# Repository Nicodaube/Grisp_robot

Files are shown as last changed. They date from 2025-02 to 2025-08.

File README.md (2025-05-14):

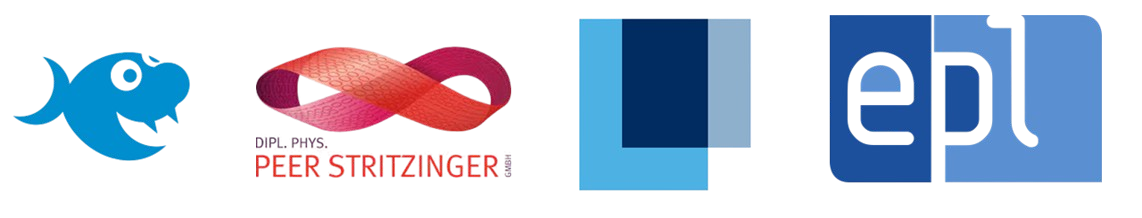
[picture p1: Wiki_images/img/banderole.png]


# GRiSP2 Robot

## Introduction

This project is an extension of the master thesis made by Francois Goens and Cédric Ponsard (link [here](https://github.com/FrancoisGgg/balancing_robot) (2023-2024)). It is done in the context of a new master thesis by Nicolas Daube and Thomas Vanbever (2024-2025). Both of these master thesis where done under the supervision of Prof. Peter Van Roy at UCLouvain. The goal of this project is to use [GRISP2 boards](https://github.com/grisp/grisp) (designed and comercialised by [Peer Stritzinger GMBH.](https://stritzinger.com/)) and the [Hera](https://github.com/Nicodaube/hera) framework to create a robot capable of standing upright (last master thesis) and to know its own position in an assembly of rooms (current project). The robot, and its associated sensors, need to know at all time the position of the robot in the system of rooms. Each sensor knows all the data sent by each sensors and by the robot. An other goal of this project is thus to allow each sensor to compute the position of the robot (using a Kalman Filter) at a reasonable rate. This implies that the filter must evolve over time, using the data given by the right sensors at the right time.

The project is done using Erlang OTP (current version 27.2.4). If you want more informations about the, project, visit our the [Wiki](https://github.com/Nicodaube/Grisp_robot/wiki) section of this repository.

## Organisation

This repository is organised in several subdirectories :

* **Hardware_robot** : contains all the necessary files to build the robot. In `Hardware_robot/printing_files` you will find all the files for the prints in 3D and the laser cuts.
* **Hardware_sensor** : Contains all the necessary files to build the sensors and their supports.
* **Laptop_controller** : contains all the code concerning the python server and controller for the robot. Note that its use is mandatory to have a fully functional system.
* **LilyGo_software** : contains all the code for the two LilyGO used in this project. They are used for communication between the robot and the controller.
* **Wiki_image** : just a directory containing all the wiki and README images.
* **balancing_robot** : contains all the code for the auto-stabilized robot.
* **electronics**: contains the files concerning the custom PCB designed for the robot.
* **sensor**: contains all the erlang code for the implementation of the sonar sensors.

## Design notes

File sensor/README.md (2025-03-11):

sensor
=====

A GRiSP application

Build
-----

    $ rebar3 compile

Deploy
------

    $ rebar3 grisp deploy -n <name> -v <version>

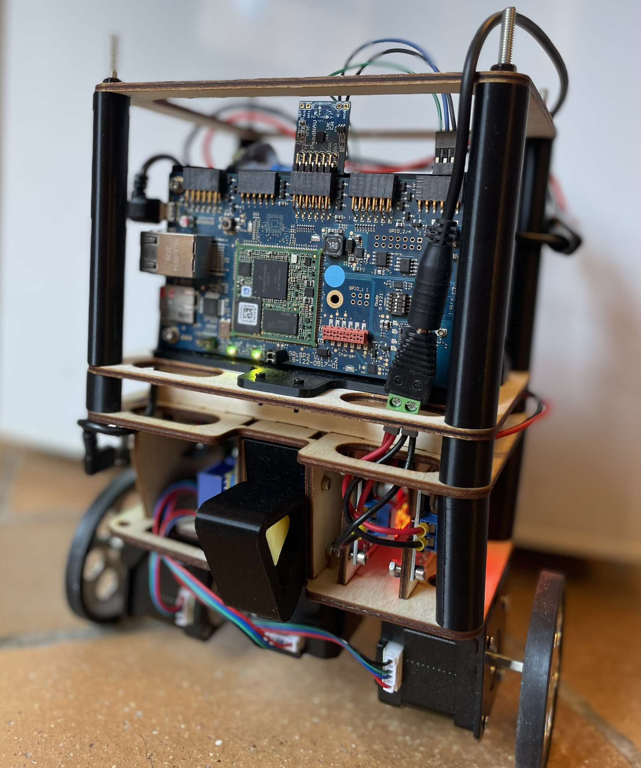
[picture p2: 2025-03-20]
Wiki_images/img/Robot.jpg

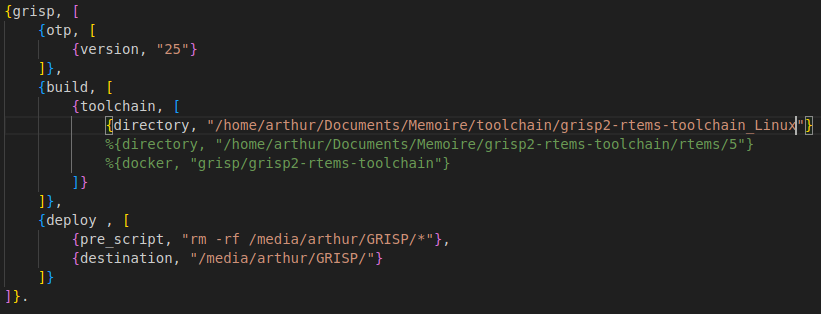
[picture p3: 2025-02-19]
Wiki_images/img/toolchain.png

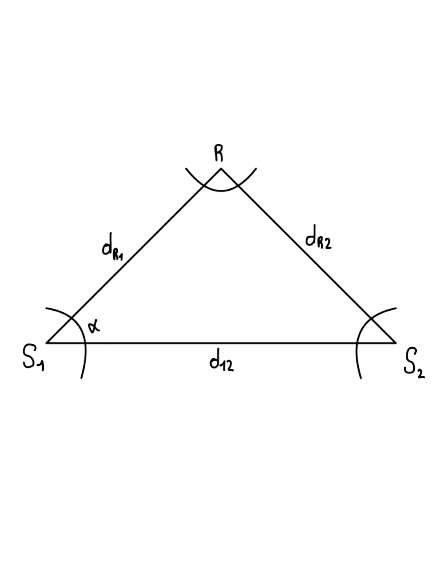
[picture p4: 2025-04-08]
Wiki_images/img/CosineLaw.png

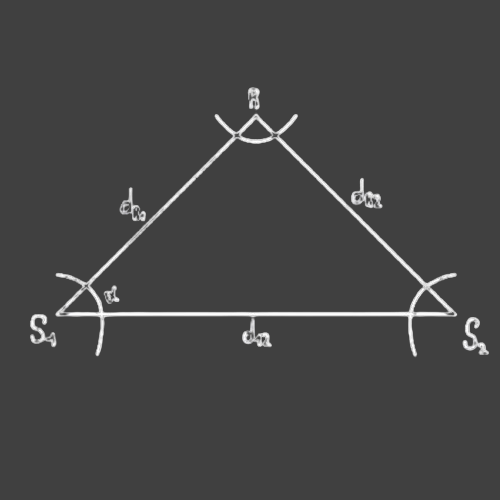
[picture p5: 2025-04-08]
Wiki_images/img/CosineLaw2.png

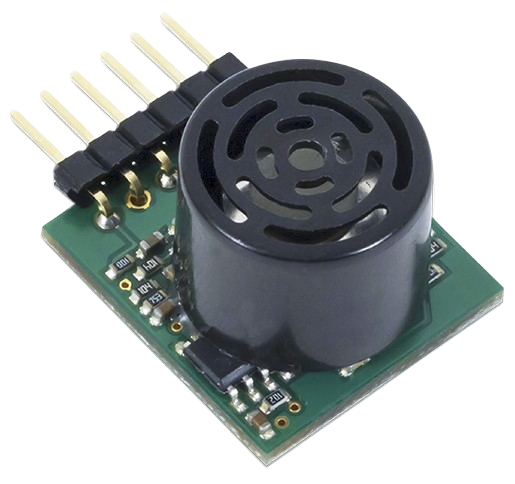
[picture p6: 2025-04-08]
Wiki_images/img/Pmod_sonar.png

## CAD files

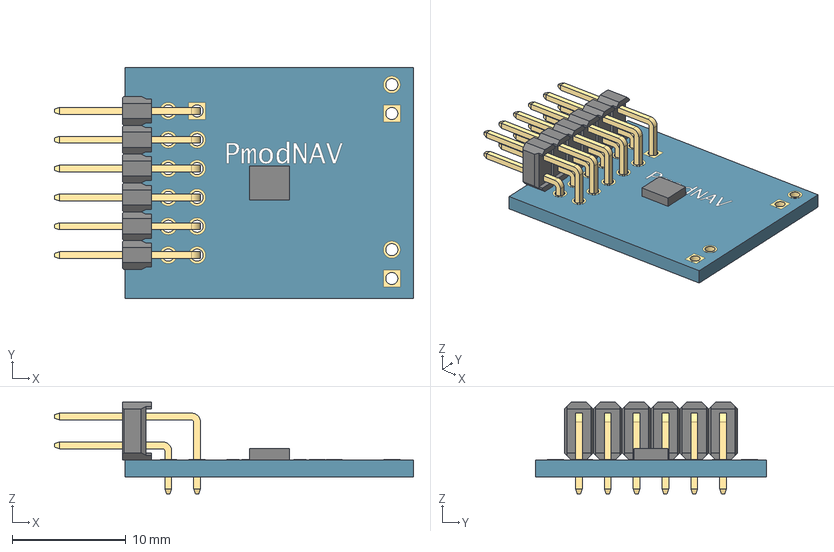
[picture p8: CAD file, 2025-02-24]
Hardware_robot/pmodnavstep/PmodNAV.stp
31.6 x 20.3 x 8.08 mm

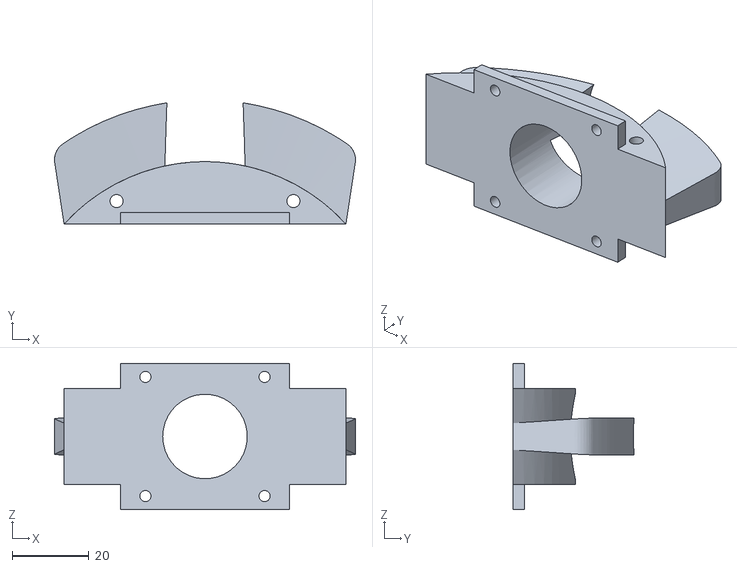
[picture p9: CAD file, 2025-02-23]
Hardware_robot/Printing_files/3D/A.STL
78.3 x 31.5 x 38.0

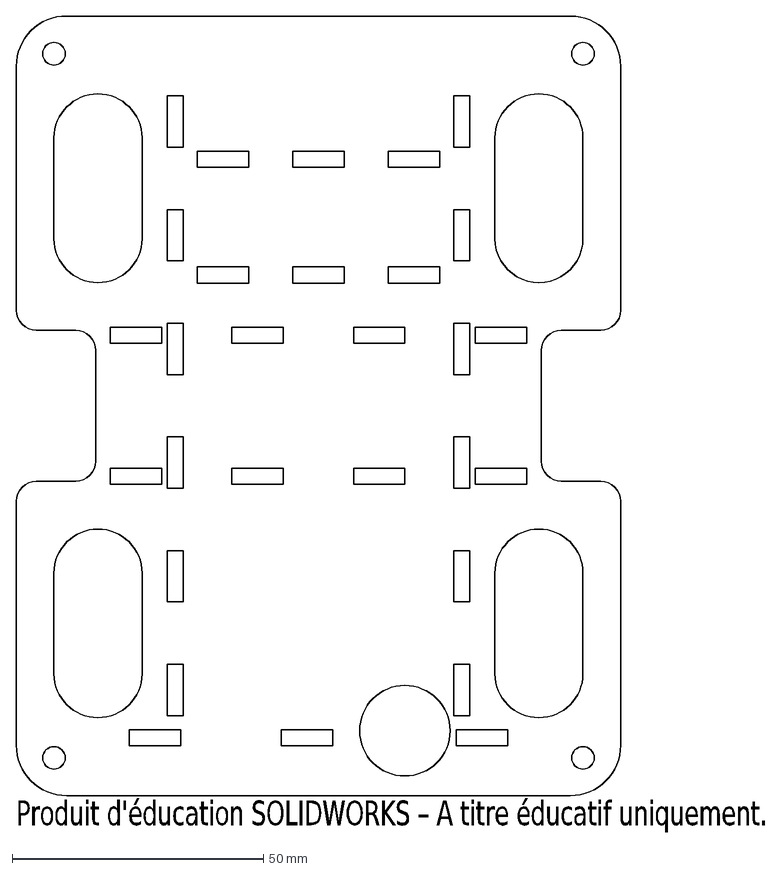
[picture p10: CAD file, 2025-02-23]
Hardware_robot/Printing_files/Laser/F.dxf
Produit d'éducation SOLIDWORKS – A titre éducatif uniquement.

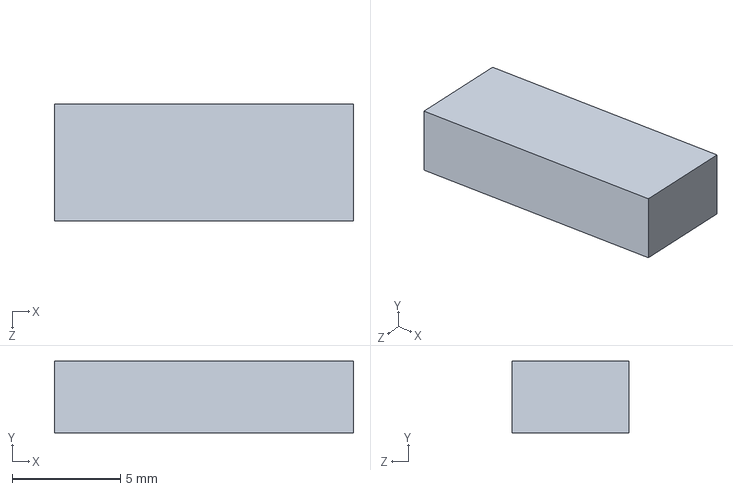
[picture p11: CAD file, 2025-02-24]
Hardware_robot/TTGO LORA32 T3 V1.6.1/antenna block.SLDPRT
13.8 x 3.30 x 5.40 mm

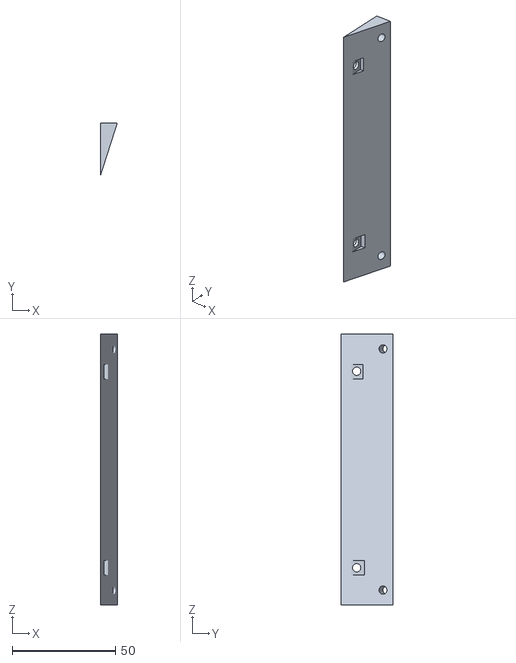
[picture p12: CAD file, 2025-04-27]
Hardware_Sensor/3D/Iece_change v11.stl
8.00 x 25.0 x 131.0

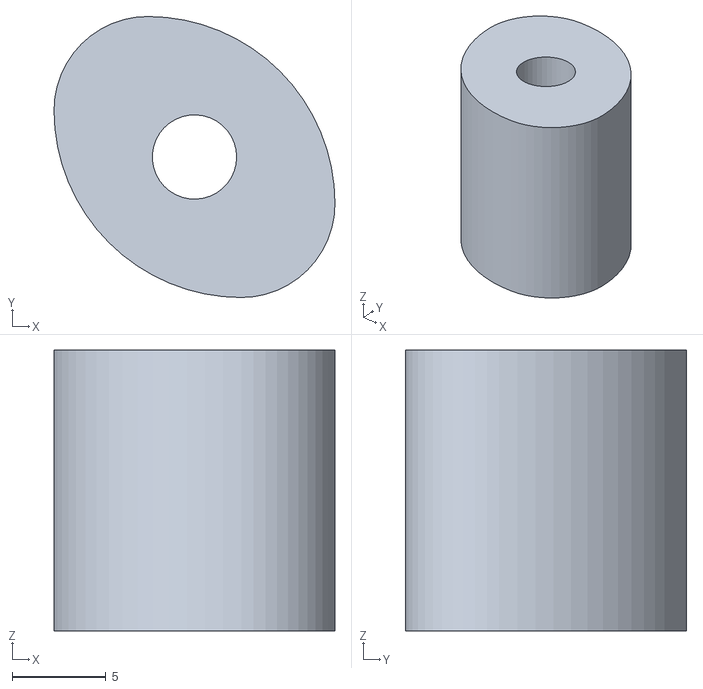
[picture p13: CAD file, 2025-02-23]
Hardware_robot/Printing_files/3D/Fx4.STL
15.0 x 15.0 x 15.0

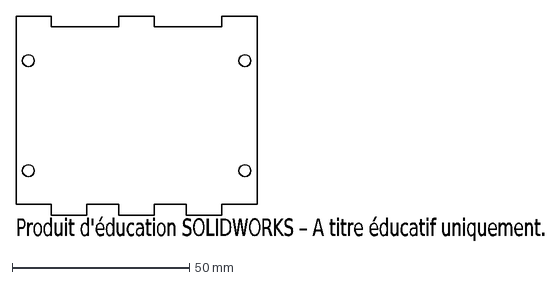
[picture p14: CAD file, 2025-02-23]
Hardware_robot/Printing_files/Laser/E.DXF
Produit d'éducation SOLIDWORKS – A titre éducatif uniquement.

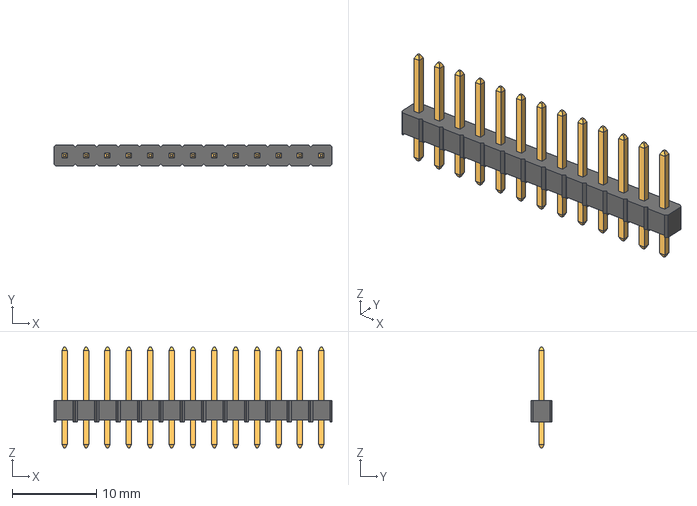
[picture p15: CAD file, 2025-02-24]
Hardware_robot/TTGO LORA32 T3 V1.6.1/13-Pin Header - Male - 2.54mm.step
33.0 x 2.54 x 11.9 mm

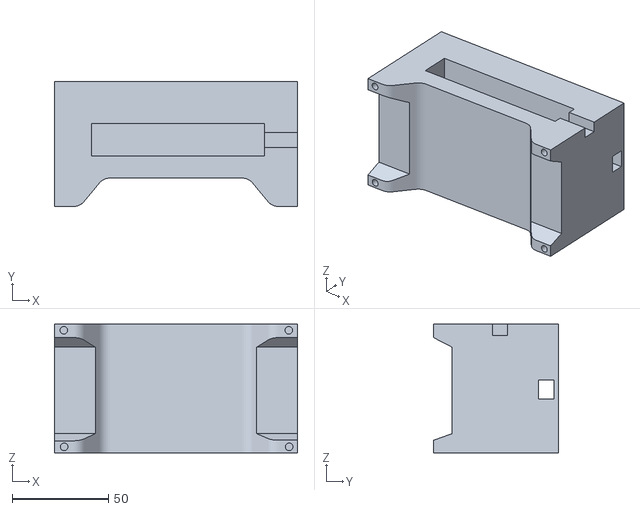
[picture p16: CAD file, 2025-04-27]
Hardware_Sensor/3D/Sensor_piece v15.stl
126.5 x 65.0 x 67.0

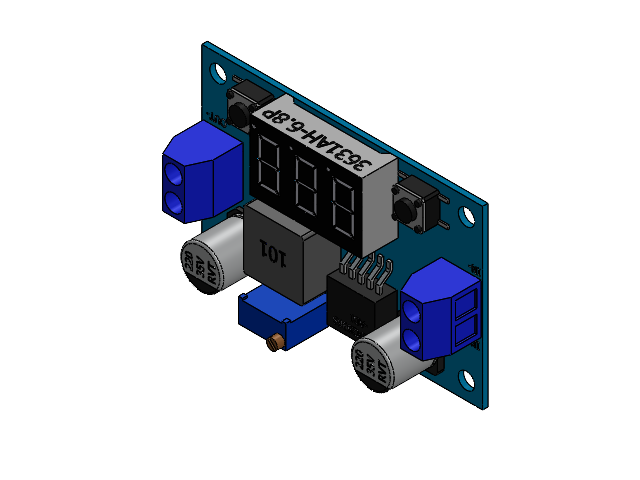
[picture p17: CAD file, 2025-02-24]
Hardware_robot/CAD_robot/CN2596-2_V2.SLDASM
CN2596-2_1.stp
LM2596S-ADJ.stp
3631AH-6.8P.stp
PZ_PushButton.stp x 2
Trimpot_3296W.stp
CAPAE-D8.0x10.2.stp x 2

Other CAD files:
Hardware_robot/CAD_robot/TerminalBlock_Phoenix_MKDS-1,5-2-5.08_1x02_P5.08mm_Horizontal.SLDASM
Hardware_robot/CAD_robot/PinHeader_1x10_P2.54mm_Vertical.SLDASM
Hardware_robot/CAD_robot/PinHeader_2x06_P2.54mm_Vertical_1.SLDASM
Hardware_robot/CAD_robot/PinHeader_1x04_P2.54mm_Vertical.SLDASM
Hardware_robot/CAD_robot/PinSocket_2x06_P2.54mm_Vertical_1.SLDASM
Hardware_robot/CAD_robot/PCB_V2.SLDASM
Hardware_robot/CAD_robot/PCB_V2 PCB2.SLDPRT
Hardware_robot/CAD_robot/Bat_lat.SLDPRT
Hardware_Sensor/3D/Support coin_attache v2.stl
Hardware_robot/CAD_robot/17HE15-1504S.SLDPRT
Hardware_robot/CAD_robot/17HE15-1504S.STEP
Hardware_robot/CAD_robot/BOOST.SLDPRT
Hardware_robot/CAD_robot/Bat_top.SLDPRT
Hardware_robot/CAD_robot/BatteryPackBlue.SLDPRT
Hardware_robot/CAD_robot/Bevel_rack.SLDPRT
Hardware_robot/CAD_robot/CN2596-2.stp
Hardware_robot/CAD_robot/Coll_1.SLDPRT
Hardware_robot/CAD_robot/Coll_2.SLDPRT
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

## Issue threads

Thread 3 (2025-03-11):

[SENSORS] Automatic binding of sensors

Nicodaube, 2025-03-11:
The sensors need to be able to register to the server (Laptop) and to get access to all the other sensors.

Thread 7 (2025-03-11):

[SENSORS] Hera integration

Nicodaube, 2025-03-11:
Integrate the hera framework and hera com to do the communication and the kalman filter computing.

Closed 2025-04-08.

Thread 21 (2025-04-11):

[SENSOR] Sonar Syncing

Nicodaube, 2025-04-11:
The sensors need to synchronyze their measures to avoid disturbance.

Closed 2025-04-14.

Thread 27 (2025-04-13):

[ROBOT] Gather Robot and nav data

Nicodaube, 2025-04-13:

Nicodaube, 2025-05-27:
We'll need all those data for the kalman implementation :

-  Acceleration in X,Y,Z
-  Angular velocity in X, Y, Z
-  Sonars ground distances
-  Sonars angles
-  Robot initial position (X, Y, angle)

May be used to improve computation :
- Robot angle

Closed 2025-06-14.

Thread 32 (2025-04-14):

[SENSOR] Error with persistent_term:get on configuration

Nicodaube, 2025-04-14:

Nicodaube, 2025-04-21:
Seems to have dissapeared

Closed 2025-04-21.

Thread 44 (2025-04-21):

[SENSOR] [ROBOT] Create basic new kalman filter

Nicodaube, 2025-04-21:

Vanboucle, 2025-04-28:
We need to create a function to capture the correct sonar values in order to create the quaternion matrices. Then we need to retrieve all the values from the robot. Speed, acceleration, angular velocity. So that we know where it is in space.

Closed 2025-06-14.

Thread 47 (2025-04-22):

[3D ]Pieces use for the sensor

Vanboucle, 2025-04-22:
We have separated the sensor part into 3 different parts. The first is fixed to the wall. The second is the main part where the battery, the Boost controller and the GRISP card will be placed. The last part is the part that we can modify relatively easily in order to change the angle of inclination of the sonars.

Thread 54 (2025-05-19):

[SENSOR][ROBOT] Correct angle computation

Nicodaube, 2025-05-19:
The angle of at which the robot is at is currently wrong. The initial theory is that it is because it doesn't take into account the initial angle of the robot

Nicodaube, 2025-05-19:
There is a problem with the sonars, maybe it is because of the synchronization between them. I think one of the sensors is starving. I get here a sensor who computed 40 times the distance while the other only computed it 11 times. I must then improve the synchronization system.

Closed 2025-05-22.

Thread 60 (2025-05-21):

[SENSOR] Possible bug when hera_measure crashes

Nicodaube, 2025-05-21:
When a hera_measure module crashes, it restarts with a sequence num = 1, it should restart with the latest seq number

Nicodaube, 2025-05-21:
Possibly connected to issue #56

Nicodaube, 2025-05-21:
Solved for sonar sensor, may need to do it for the other hera_measure as well

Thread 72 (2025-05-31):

[ROBOT][SENSOR] Find a way and implement the communication inside/outside the Farraday's cage

Nicodaube, 2025-05-31:

Nicodaube, 2025-05-31:
For the communication outside to inside the cage, we can either use Ethernet port or use one of the port available on the GRiSP (UART/SPI), then we need to implement an additional way of communicating to the robot (local wifi ? An other type of IoT communication as LOra or Bluetooth ?)

Nicodaube, 2025-05-31:
The idea, for now, would be to create a local WiFI connection inside the cage using an ESP32 as router. I need to implement a switch for the sensors and the robot to switch between different connections as they go. The sensors need to try to connect to the general connection and switch to the local inside cage connection if the general connection is unavailable.

For the connection outside/inside, there are multiple possibilities. I can either create a wired connection between the sensors outside the cage and inside the cage, or use the robot as a relay (caching the latest datas and transmitting them to the sensors once inside). The problem that i see with that solution is the fact that I don't know how to contact the server if the inside is completly cut out from the outside of the cage. I then think that I need to use the wired connection and transmit all data as a gossip between sensors in different networks.

Closed 2025-07-29.

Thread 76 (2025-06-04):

[???HOTSPOT???] Implement LilyGo Hotspot

Nicodaube, 2025-06-04:
Implement the ESP32 lilygo software that will allow it to become a hotspot available for the sensors to connect to.

Nicodaube, 2025-07-01:
closed in previous pull request

Closed 2025-07-01.

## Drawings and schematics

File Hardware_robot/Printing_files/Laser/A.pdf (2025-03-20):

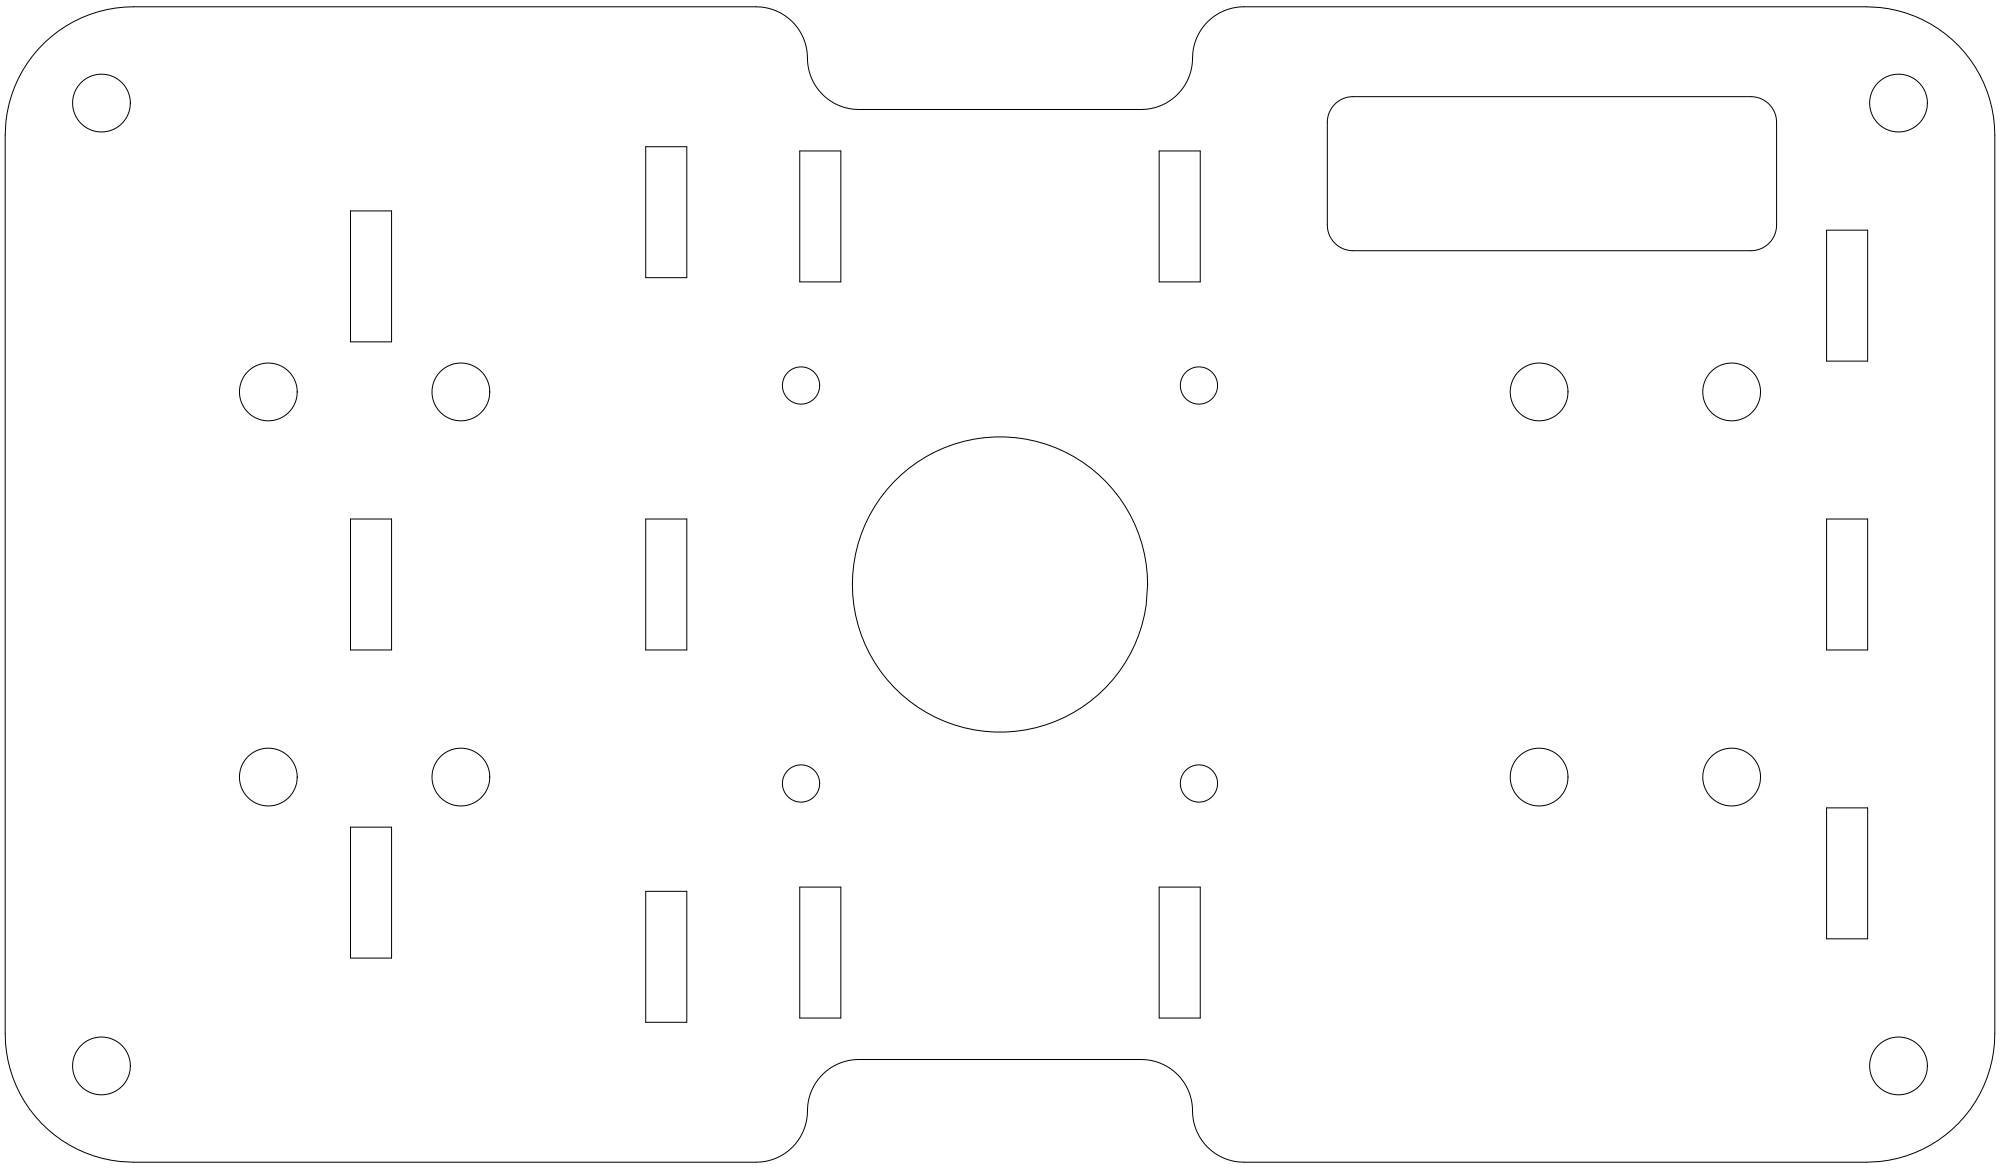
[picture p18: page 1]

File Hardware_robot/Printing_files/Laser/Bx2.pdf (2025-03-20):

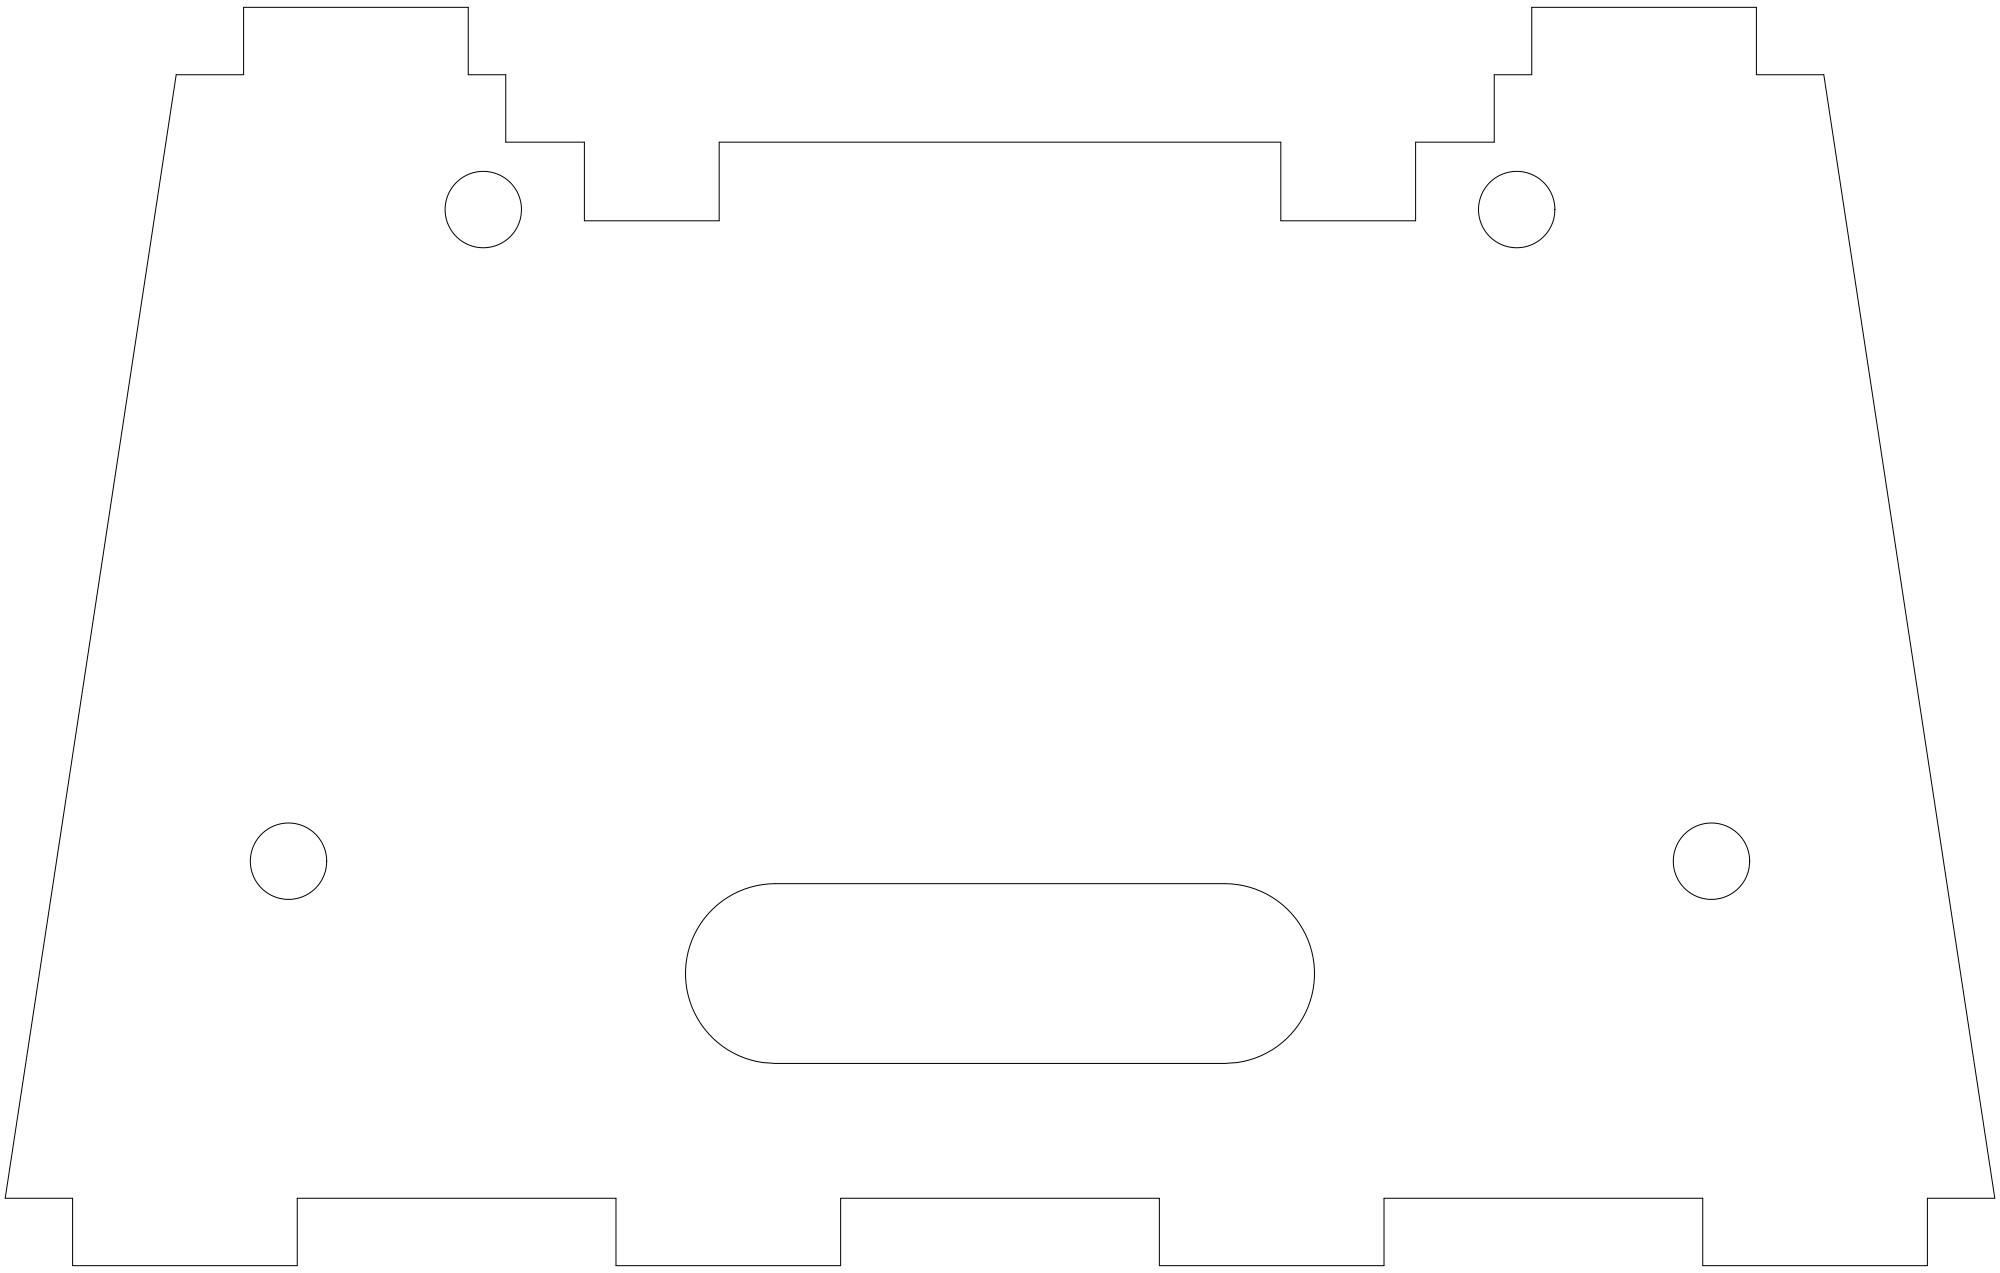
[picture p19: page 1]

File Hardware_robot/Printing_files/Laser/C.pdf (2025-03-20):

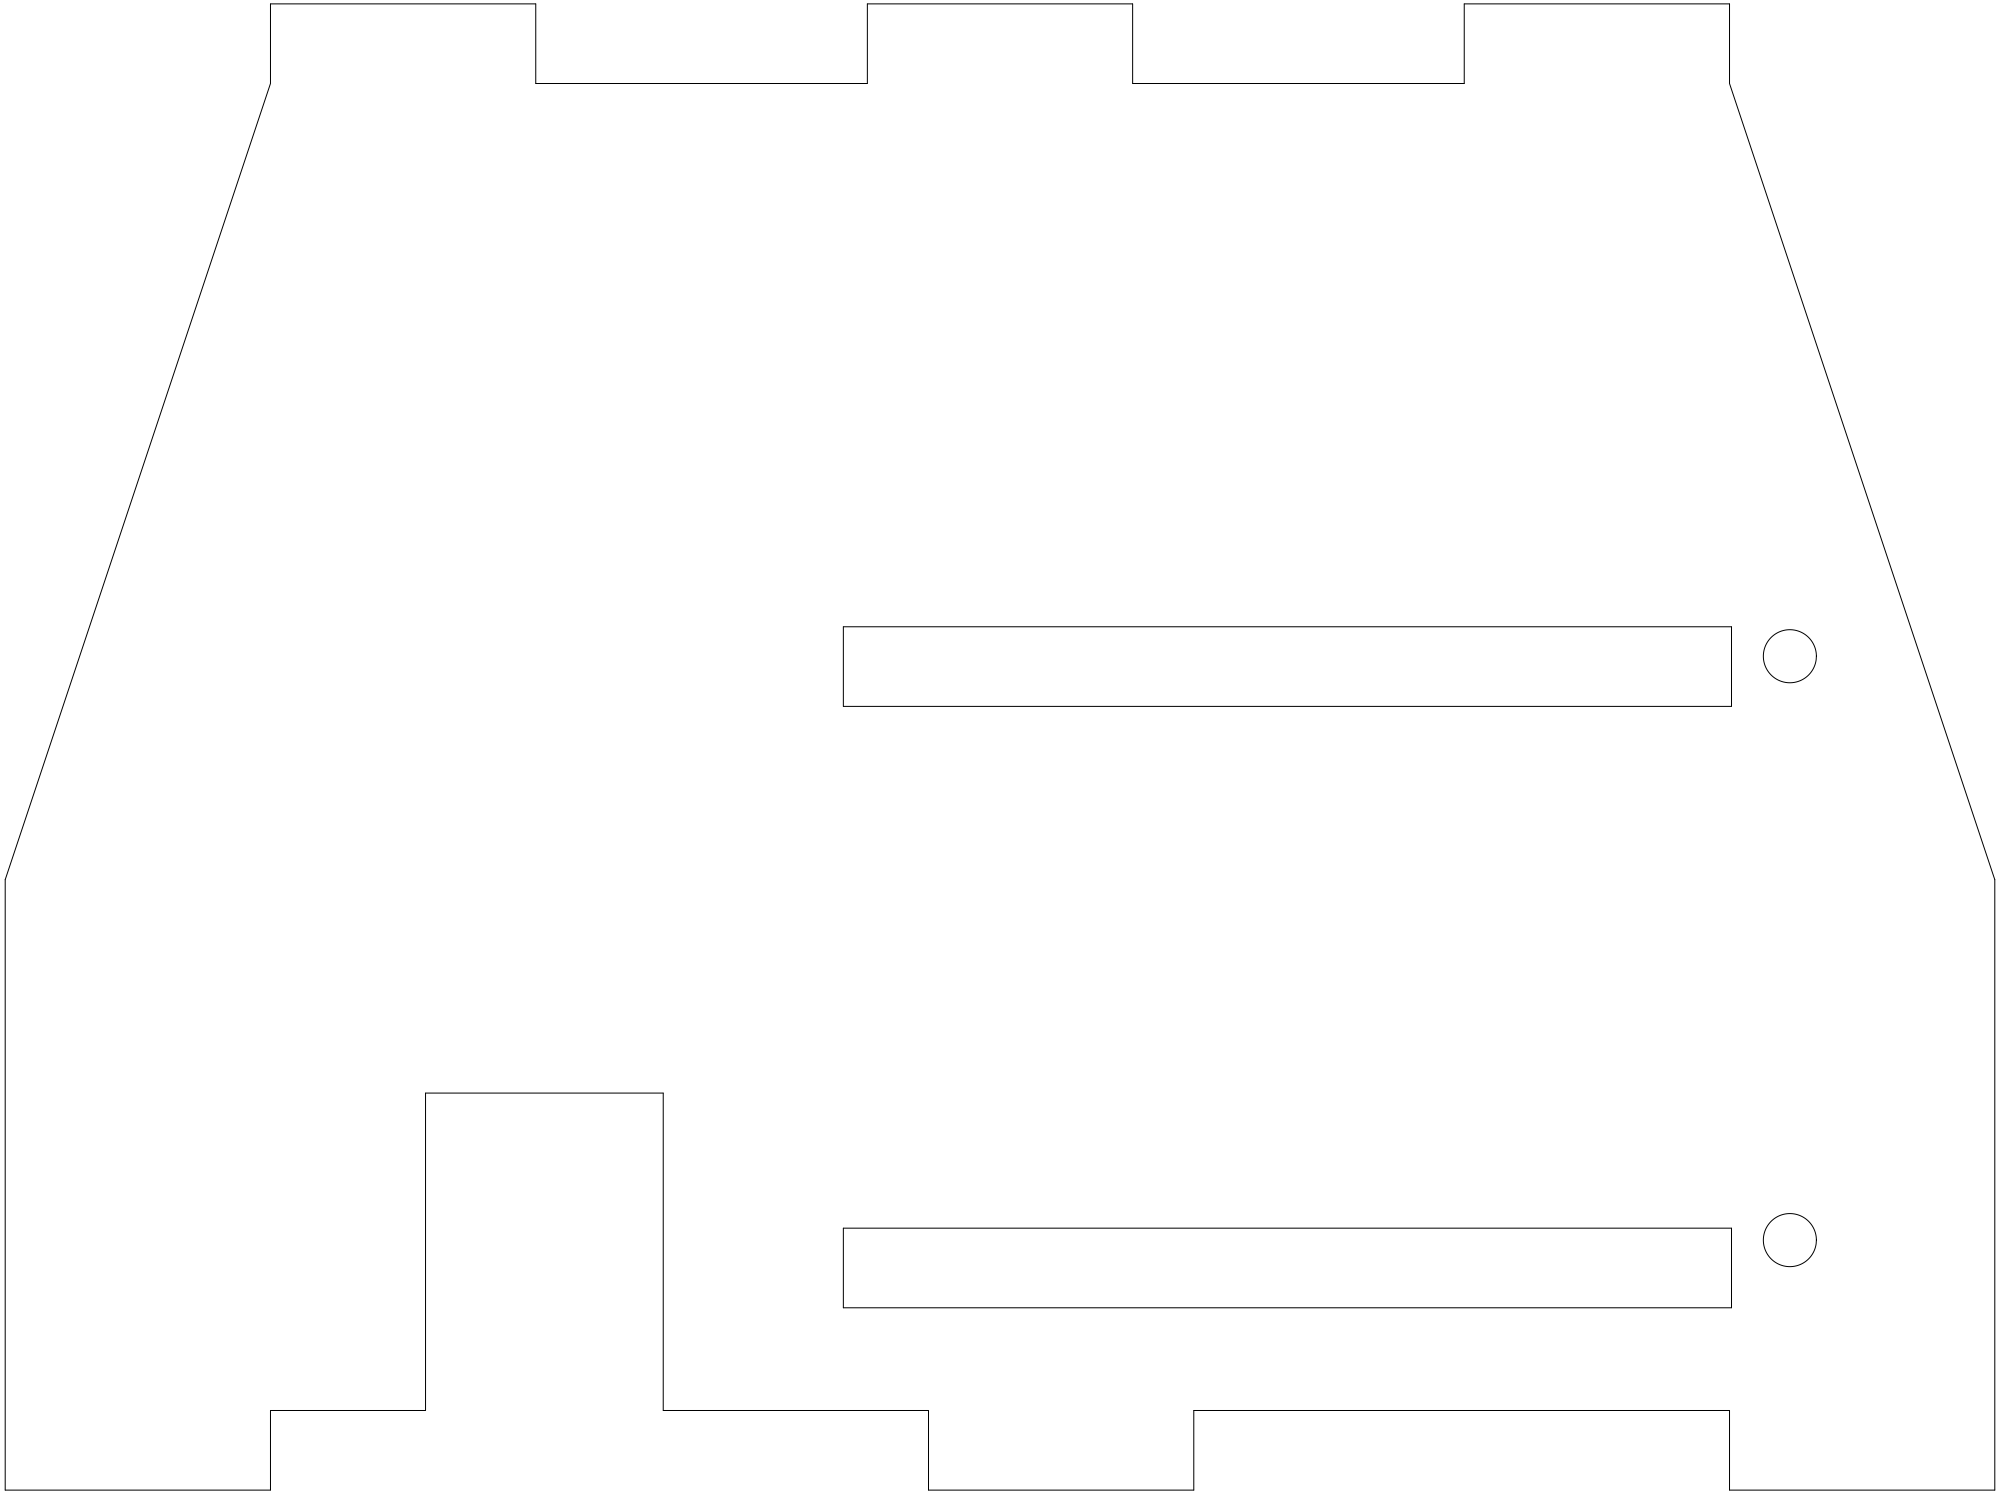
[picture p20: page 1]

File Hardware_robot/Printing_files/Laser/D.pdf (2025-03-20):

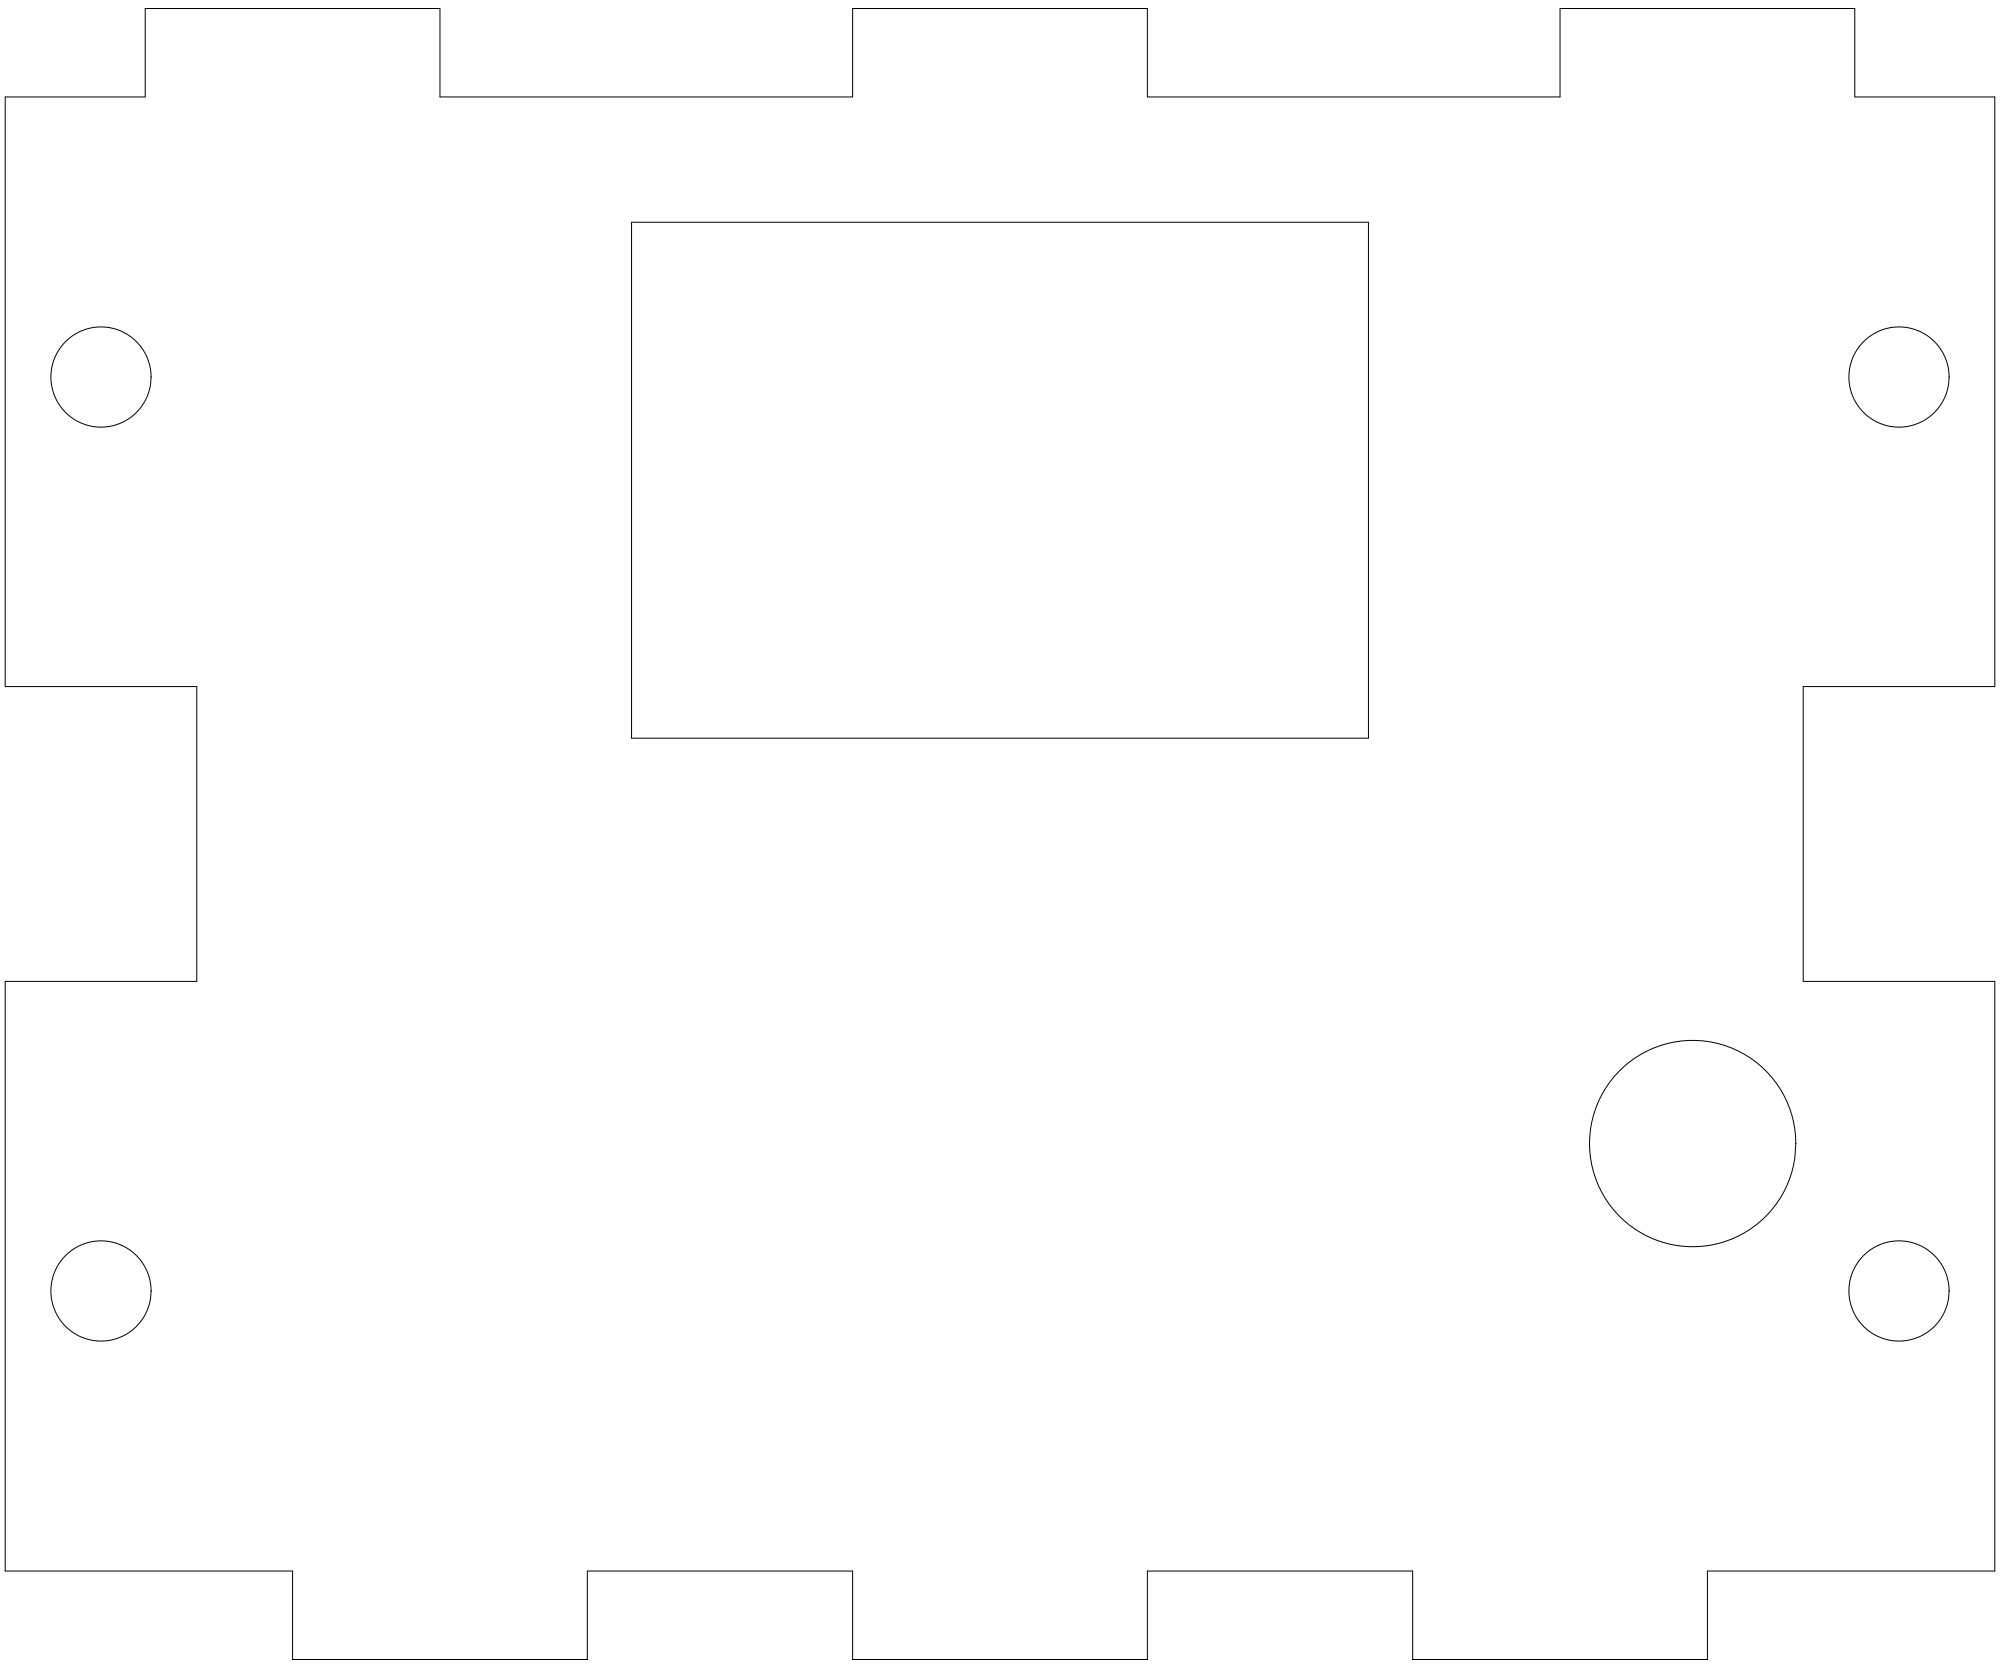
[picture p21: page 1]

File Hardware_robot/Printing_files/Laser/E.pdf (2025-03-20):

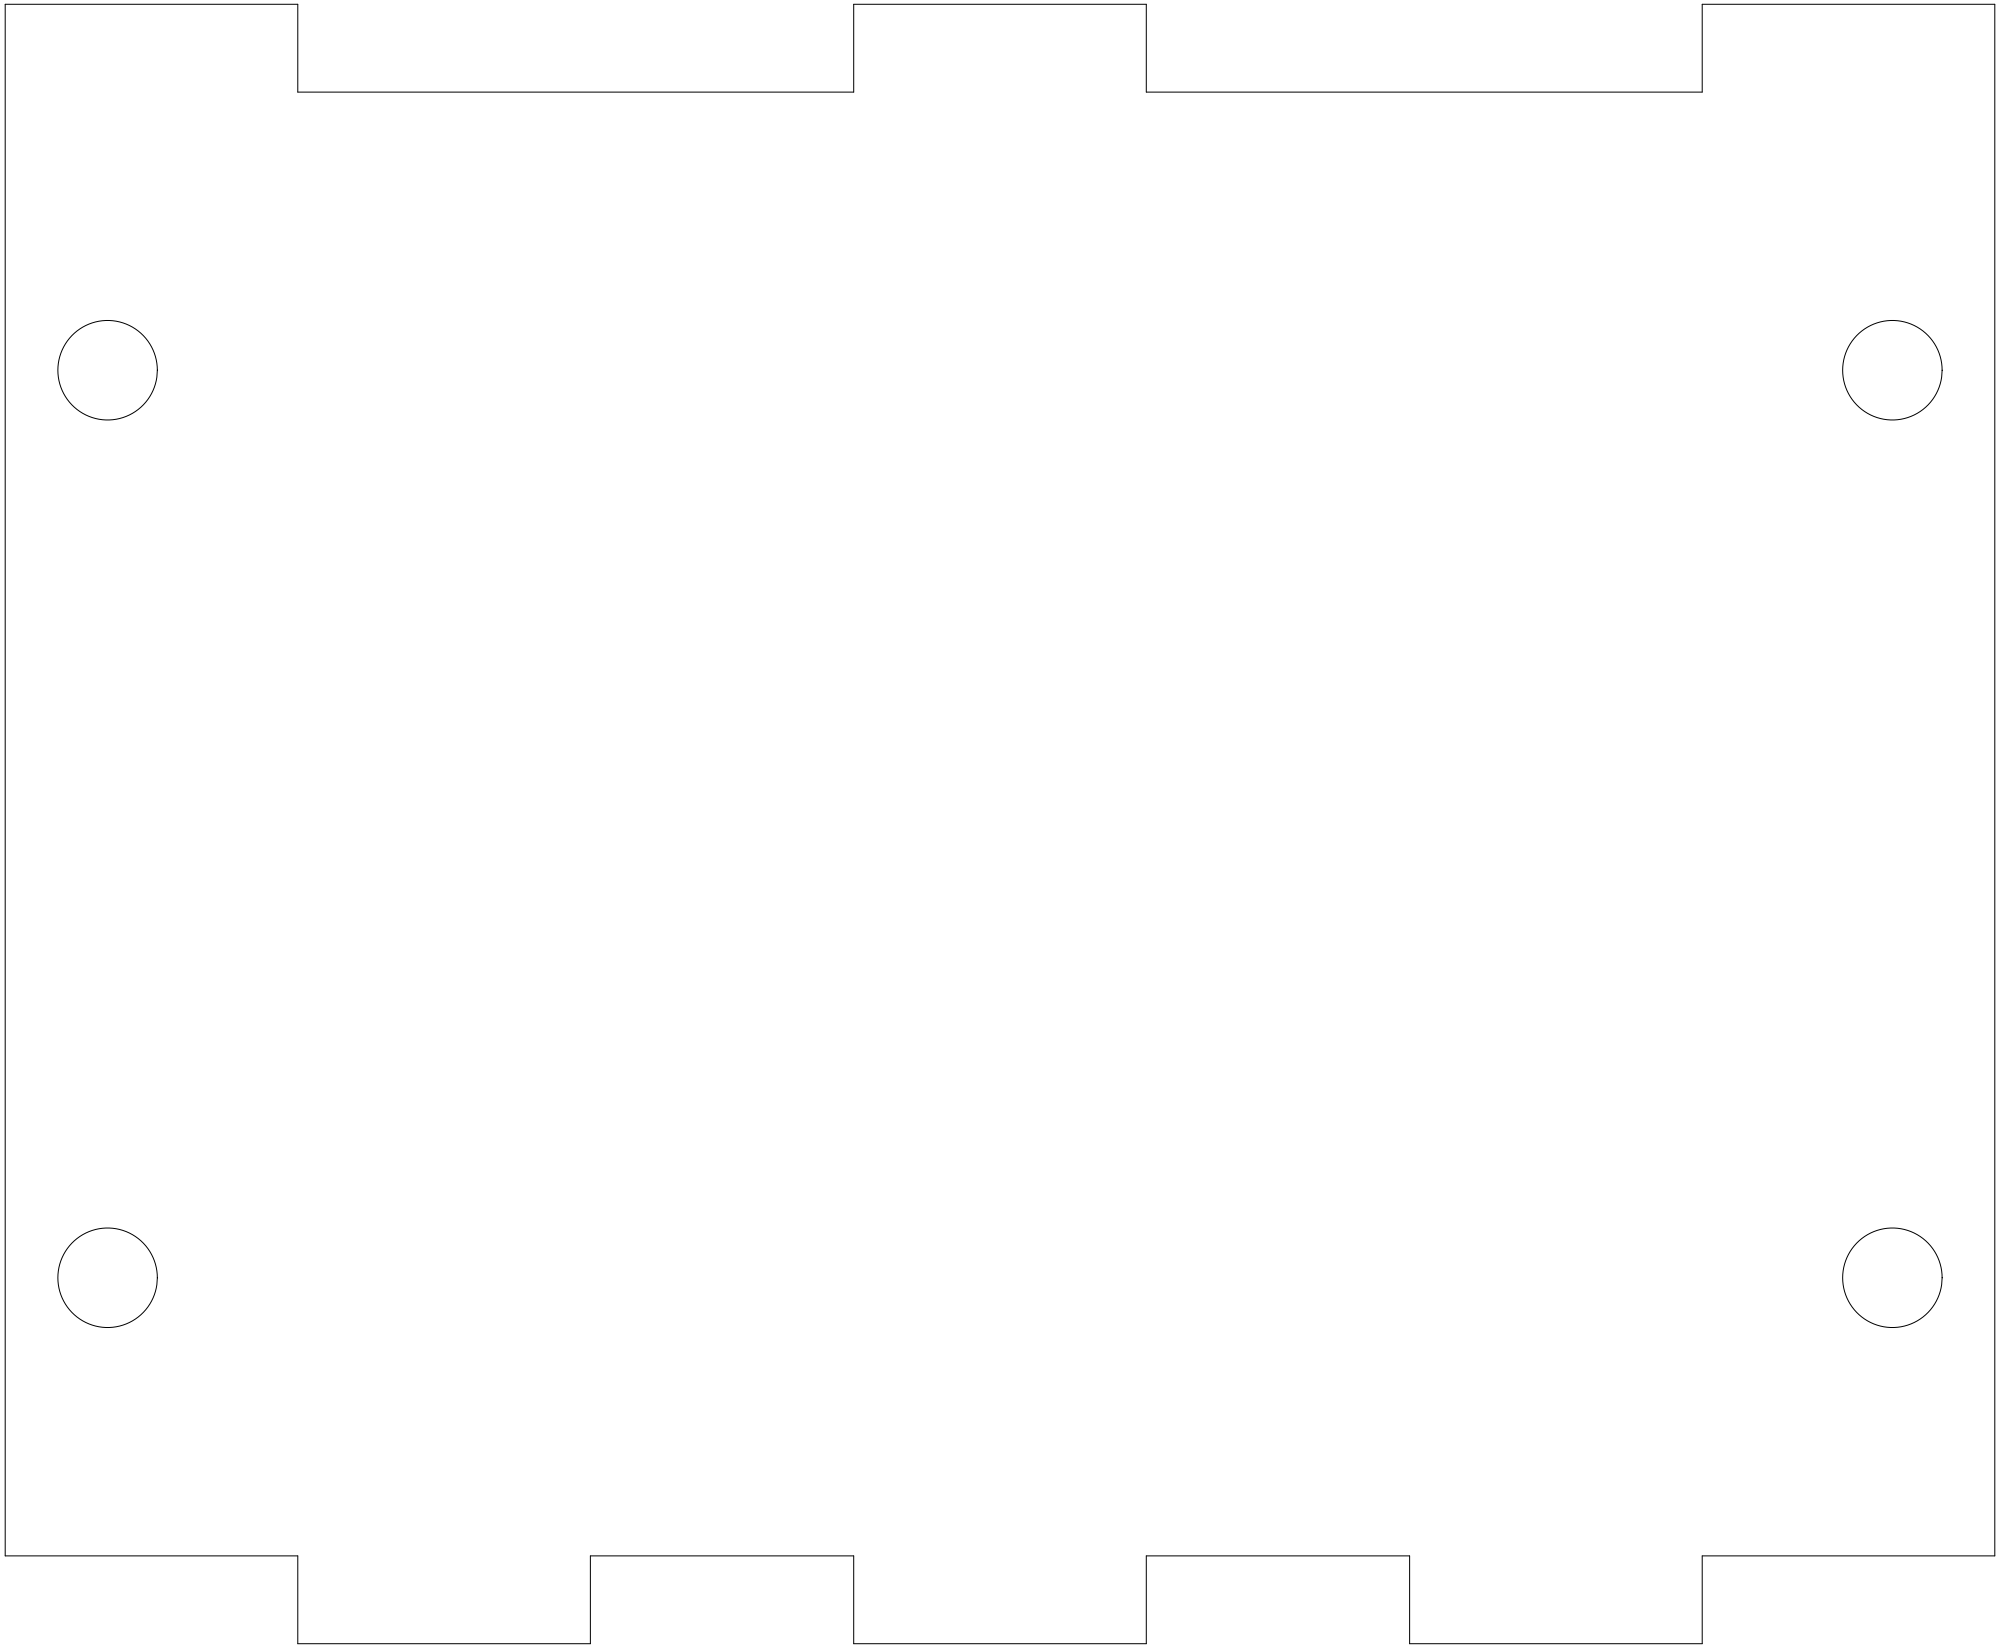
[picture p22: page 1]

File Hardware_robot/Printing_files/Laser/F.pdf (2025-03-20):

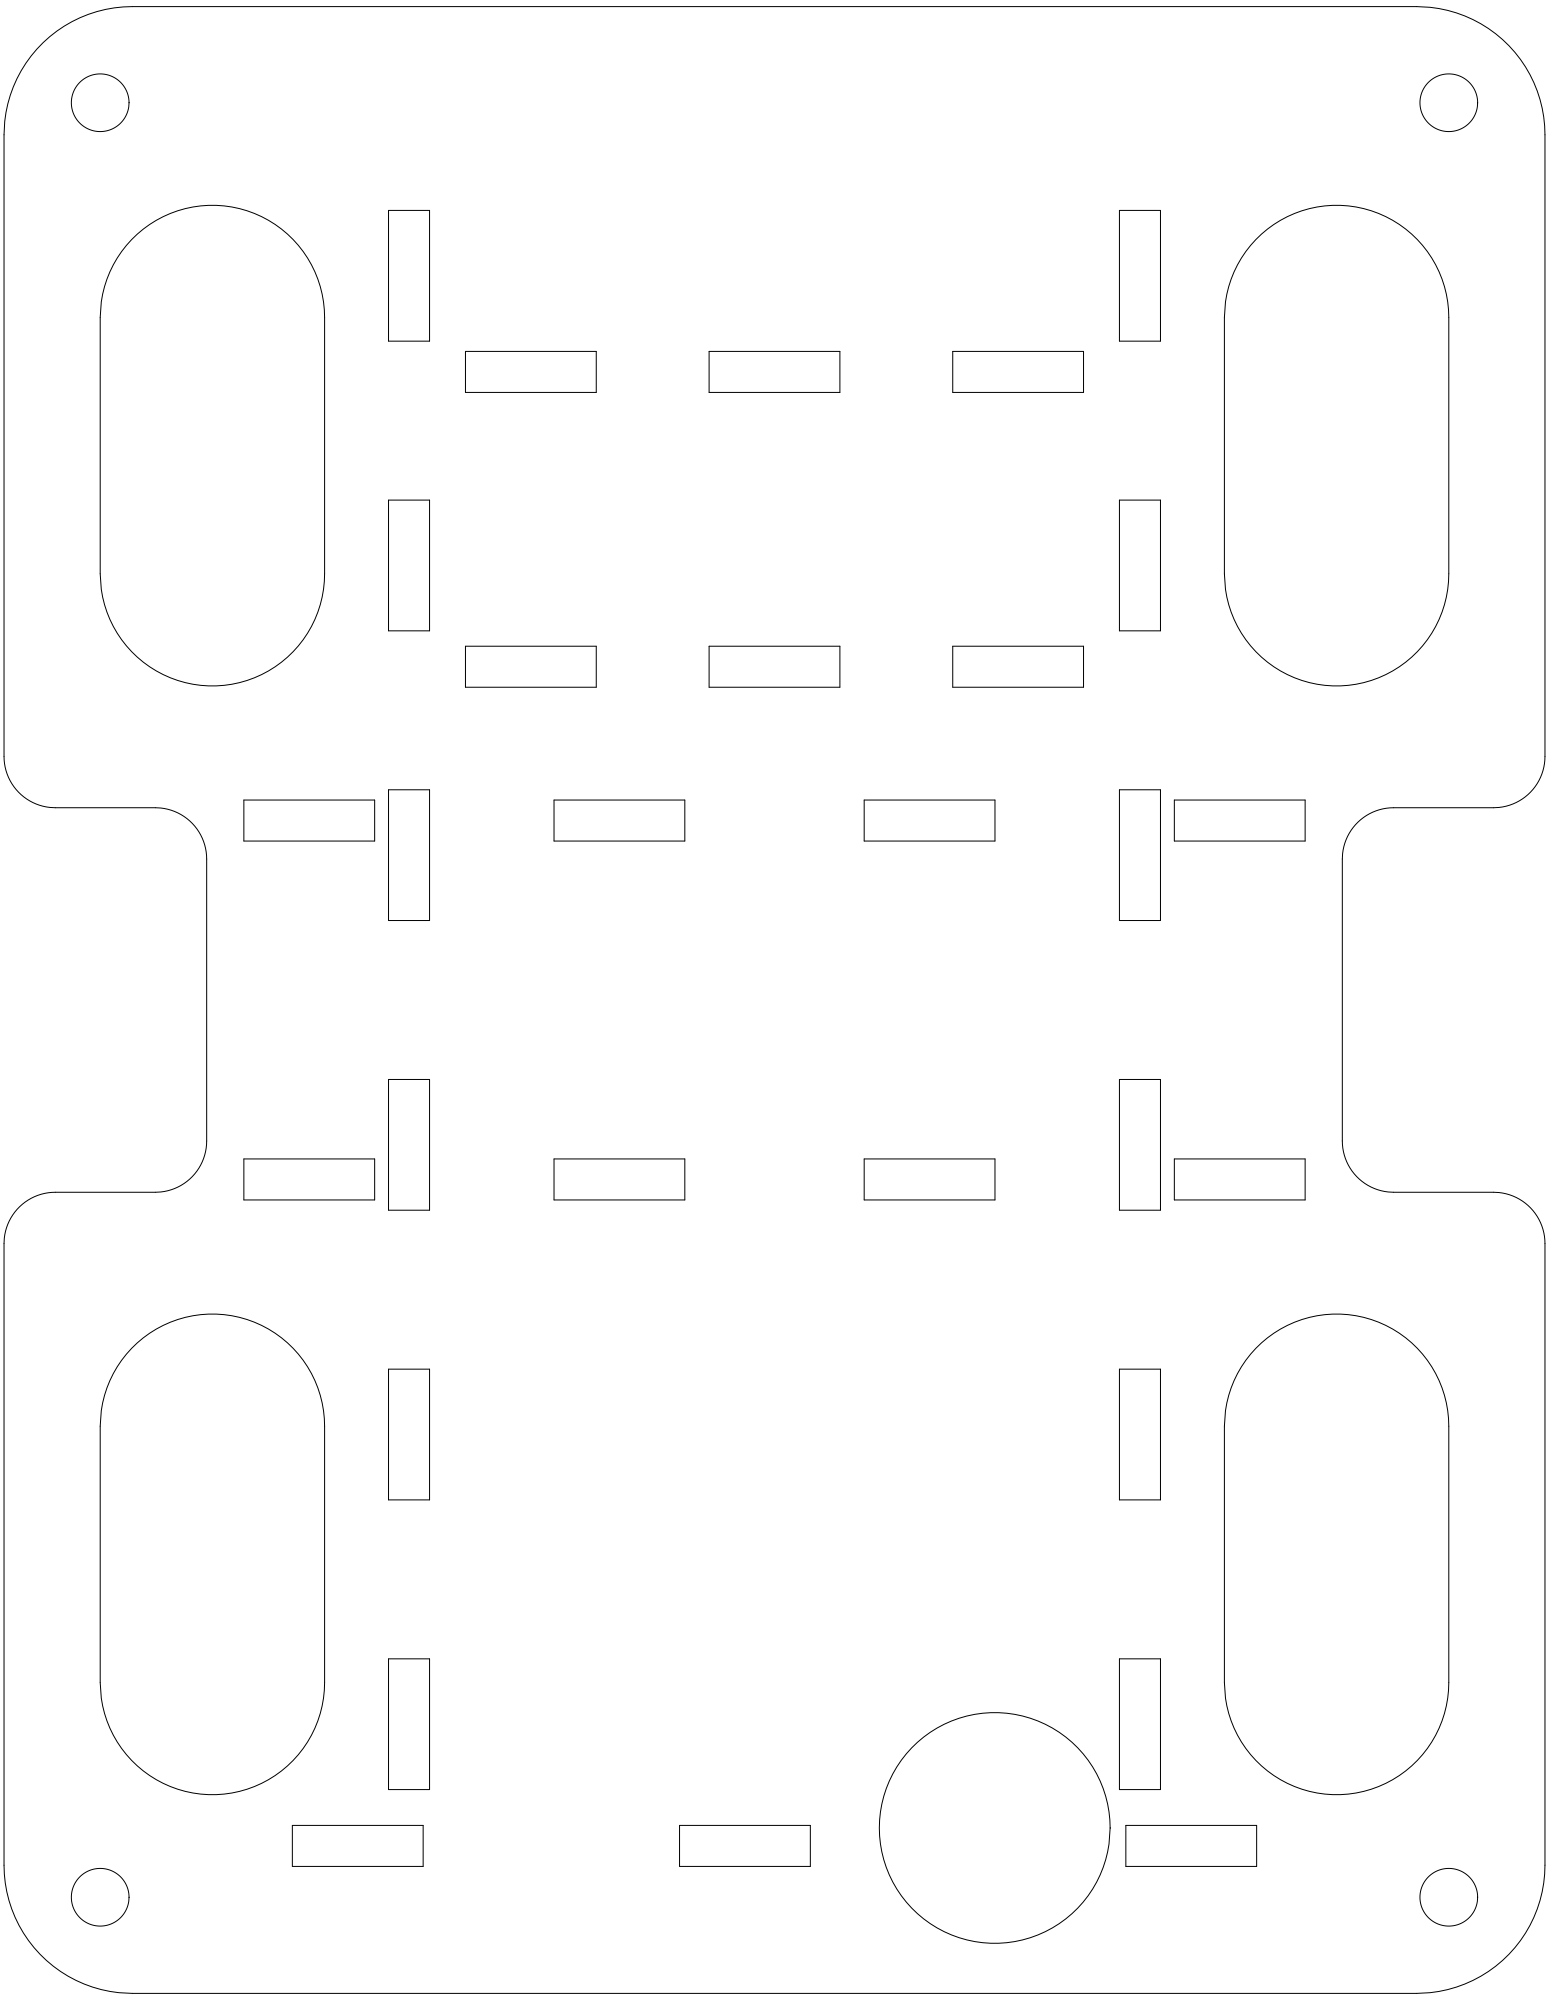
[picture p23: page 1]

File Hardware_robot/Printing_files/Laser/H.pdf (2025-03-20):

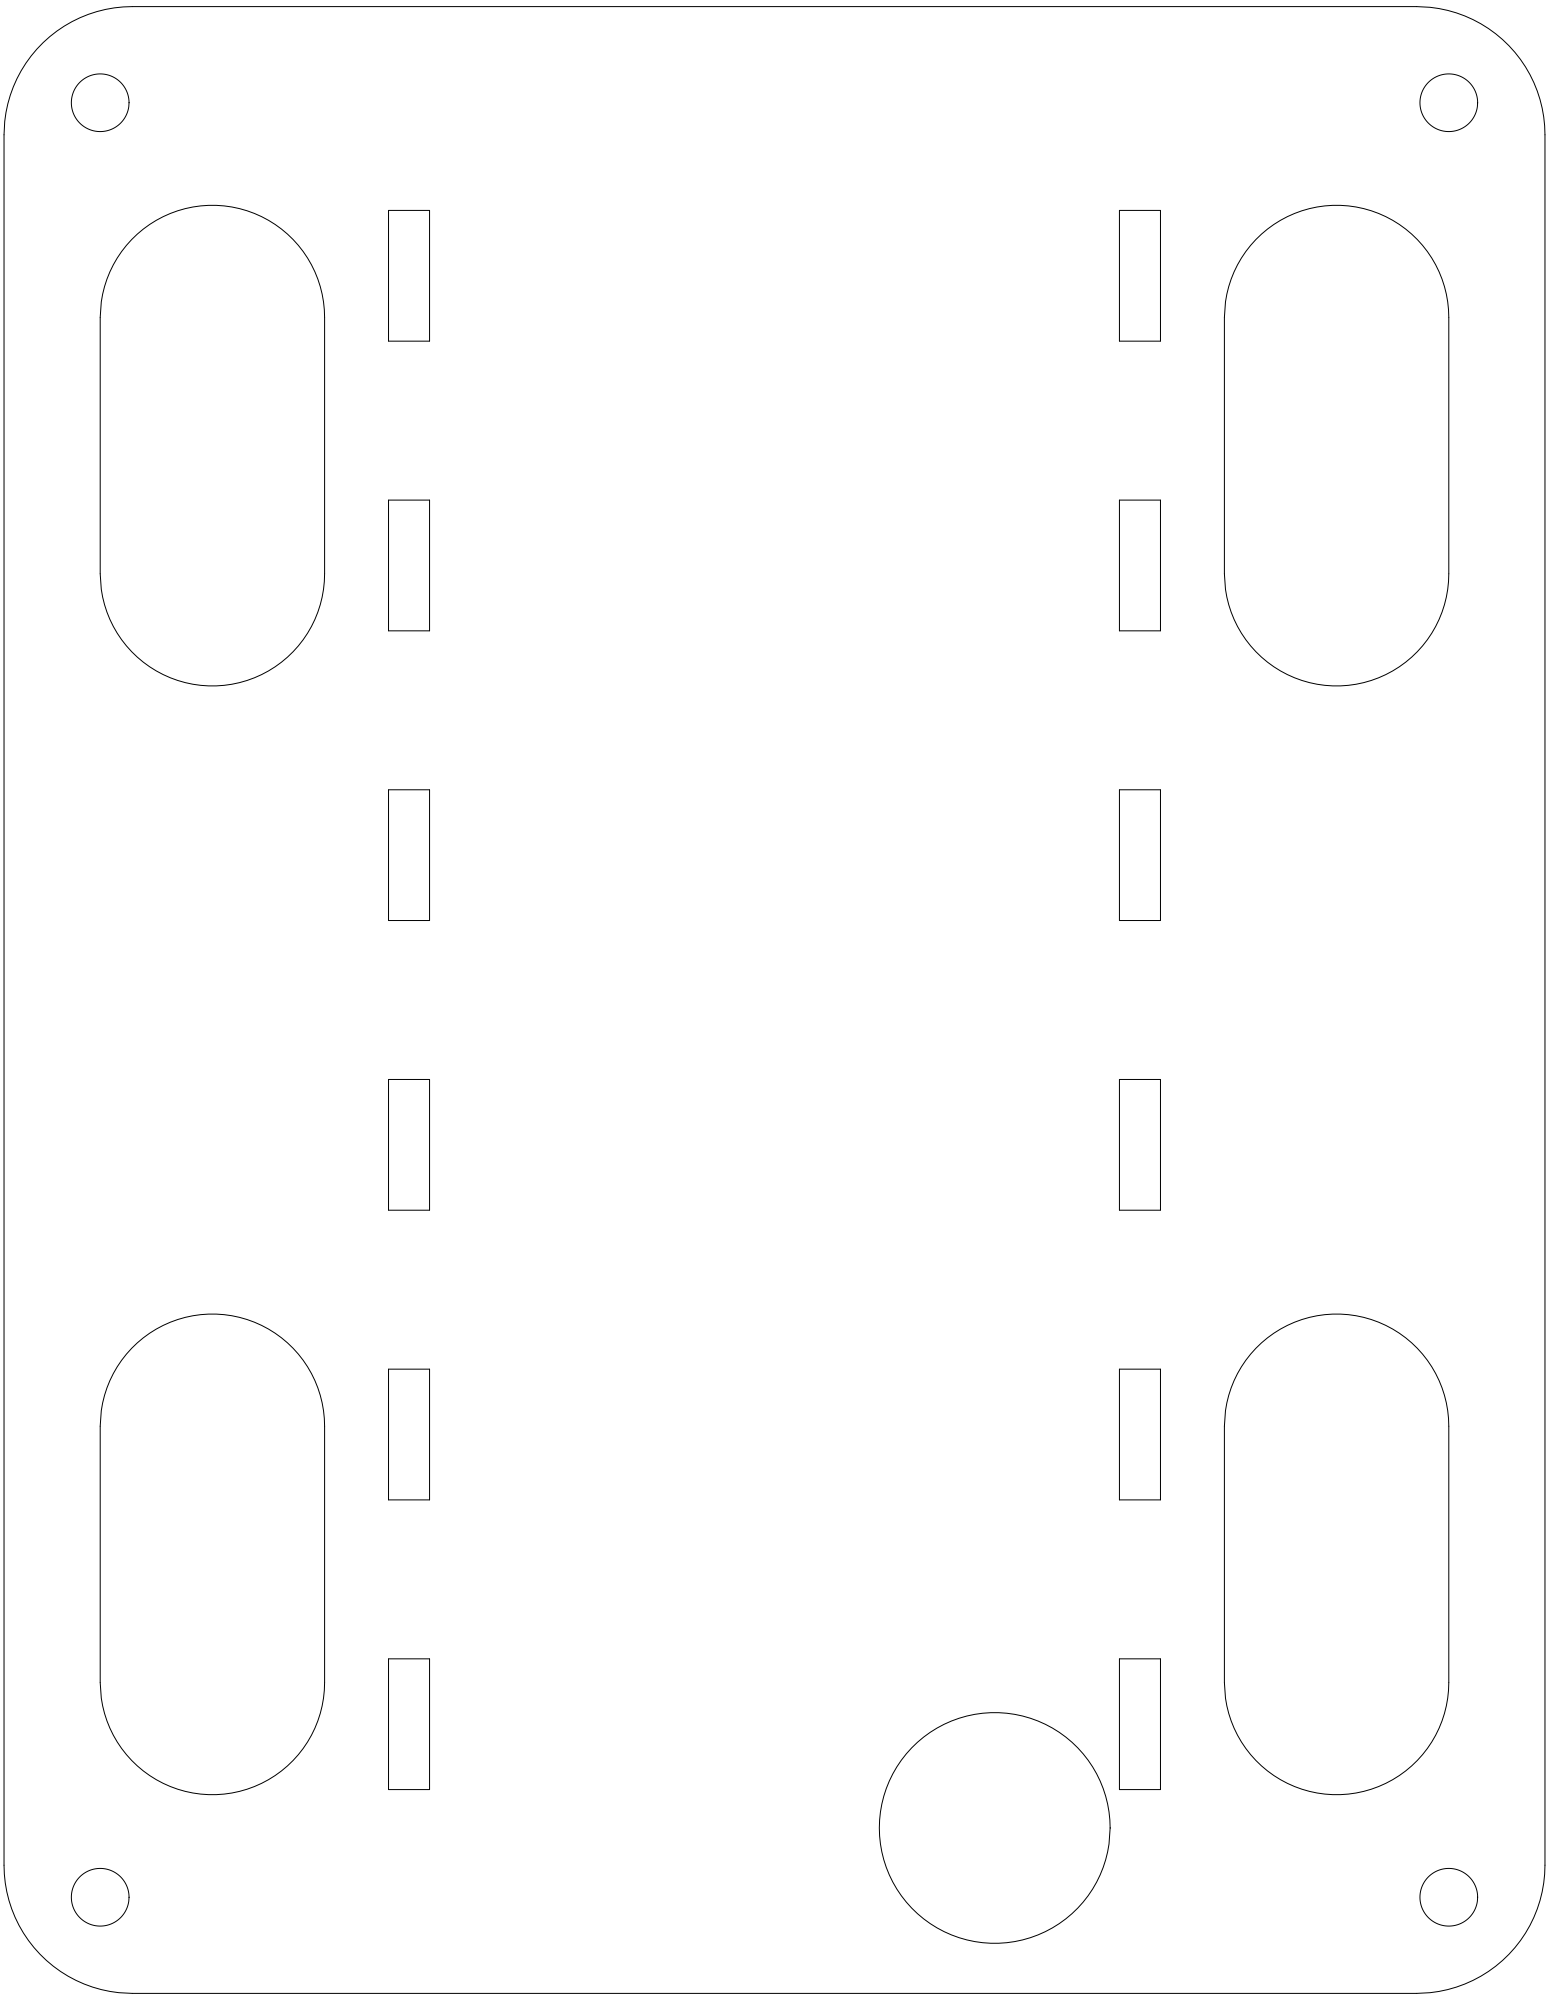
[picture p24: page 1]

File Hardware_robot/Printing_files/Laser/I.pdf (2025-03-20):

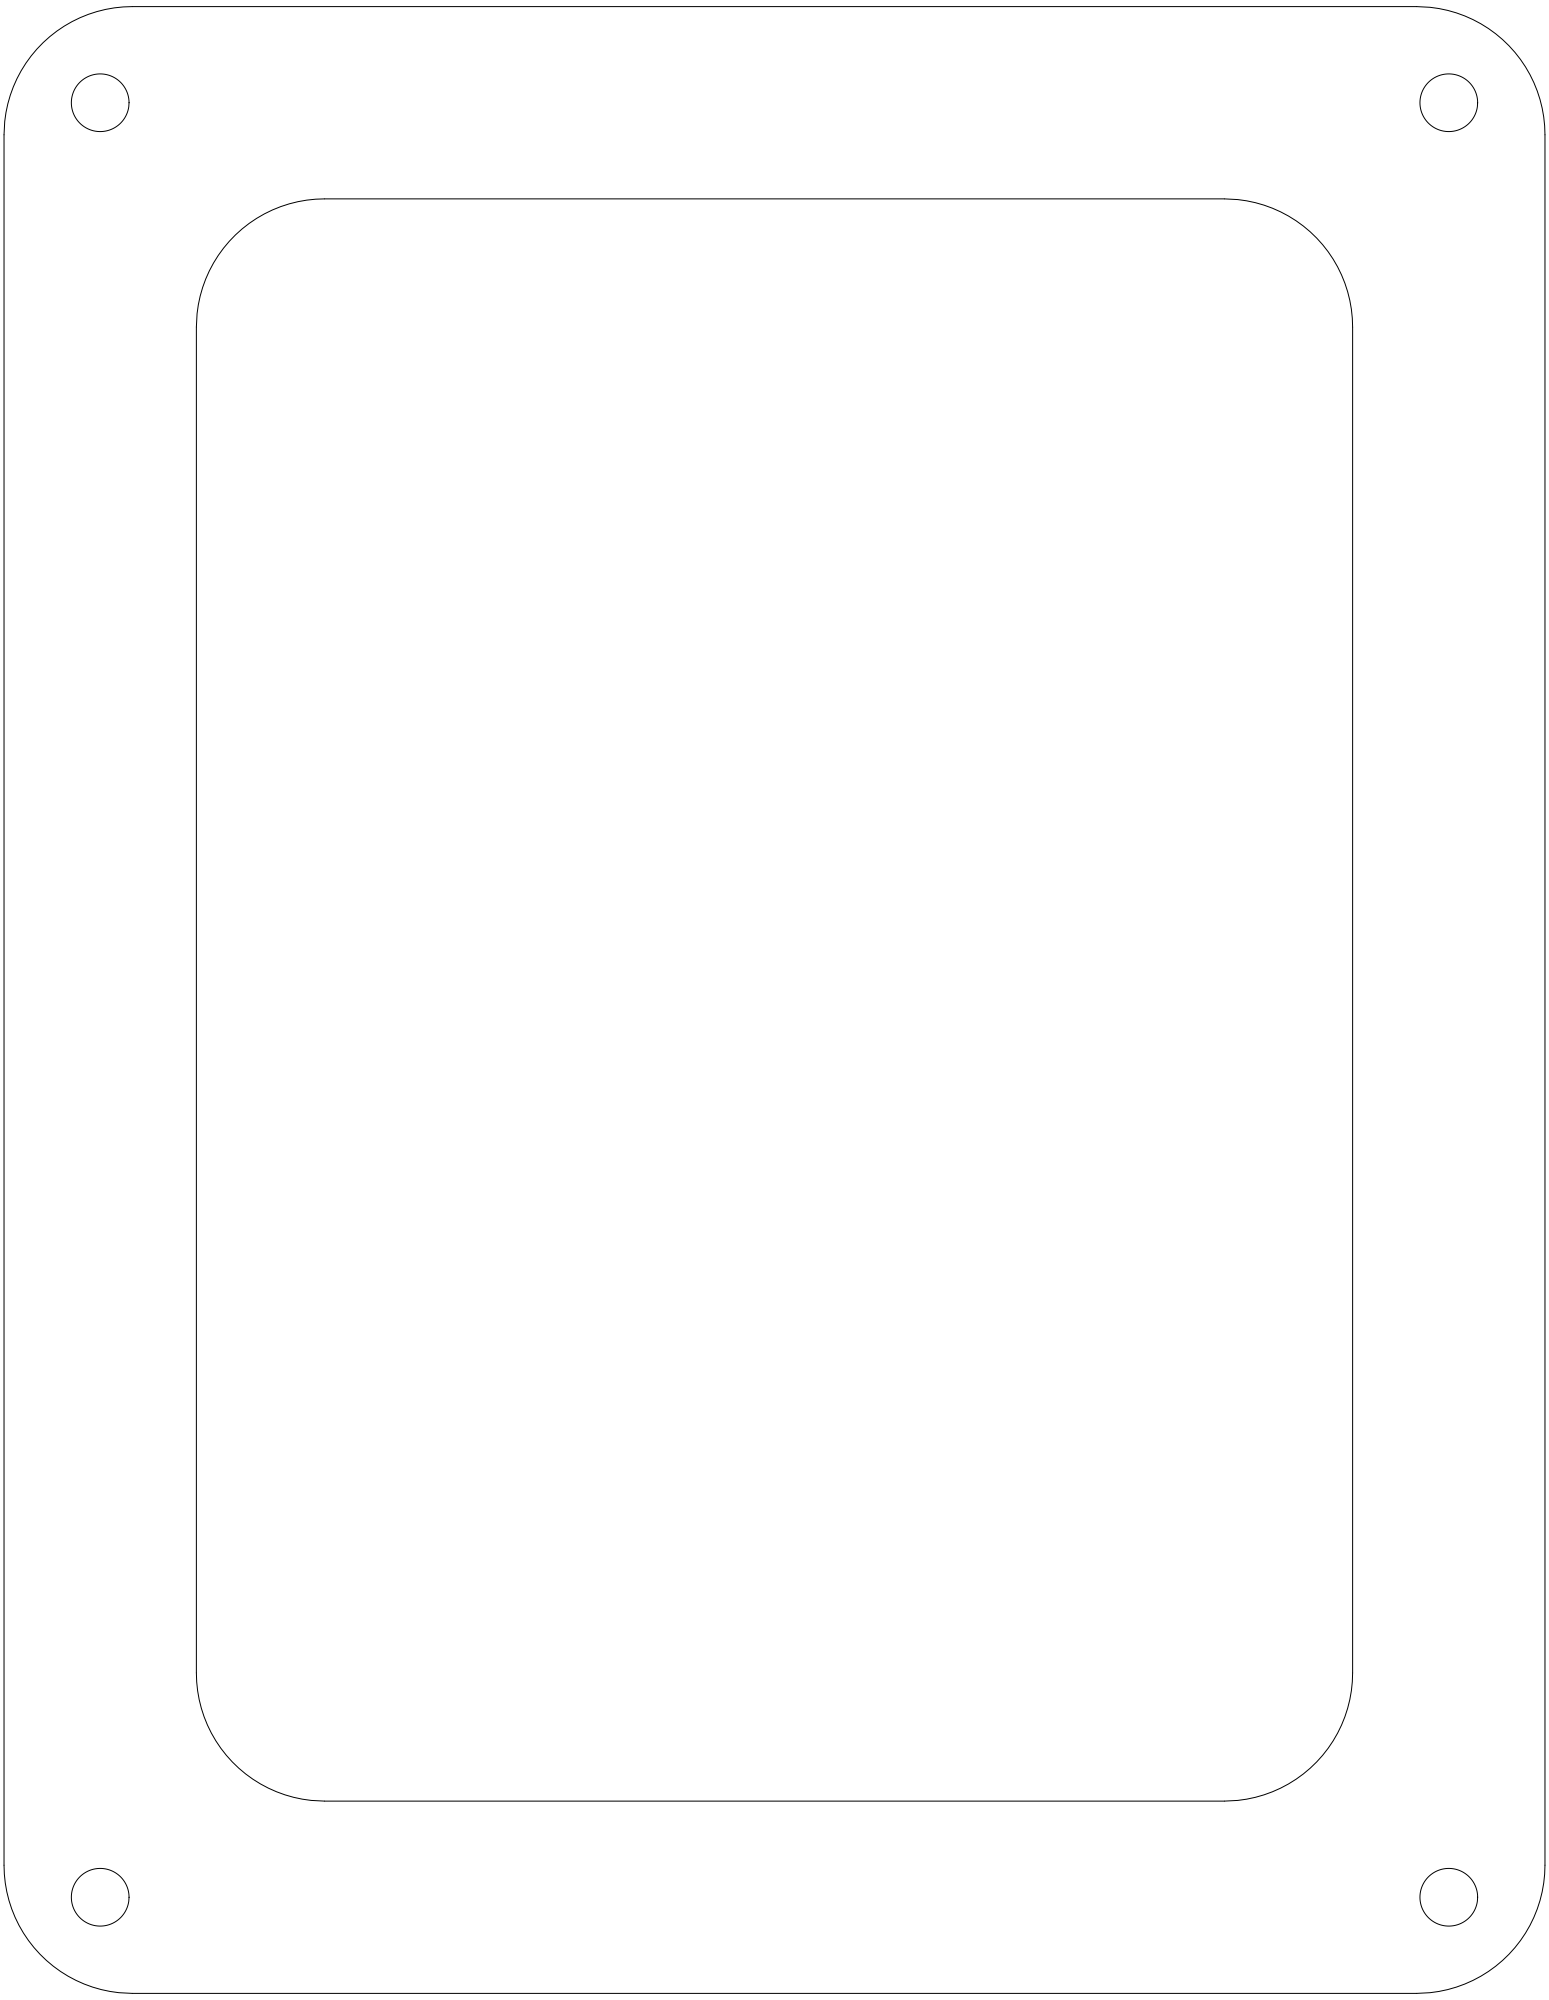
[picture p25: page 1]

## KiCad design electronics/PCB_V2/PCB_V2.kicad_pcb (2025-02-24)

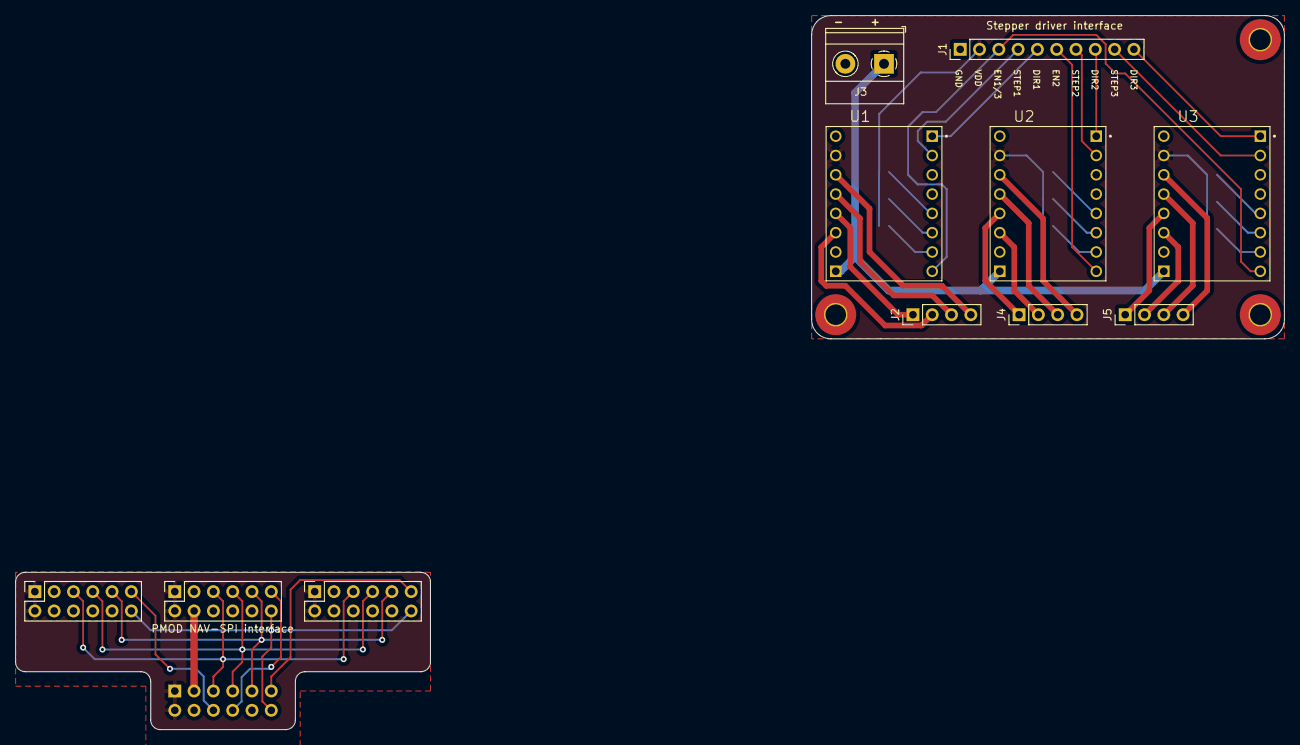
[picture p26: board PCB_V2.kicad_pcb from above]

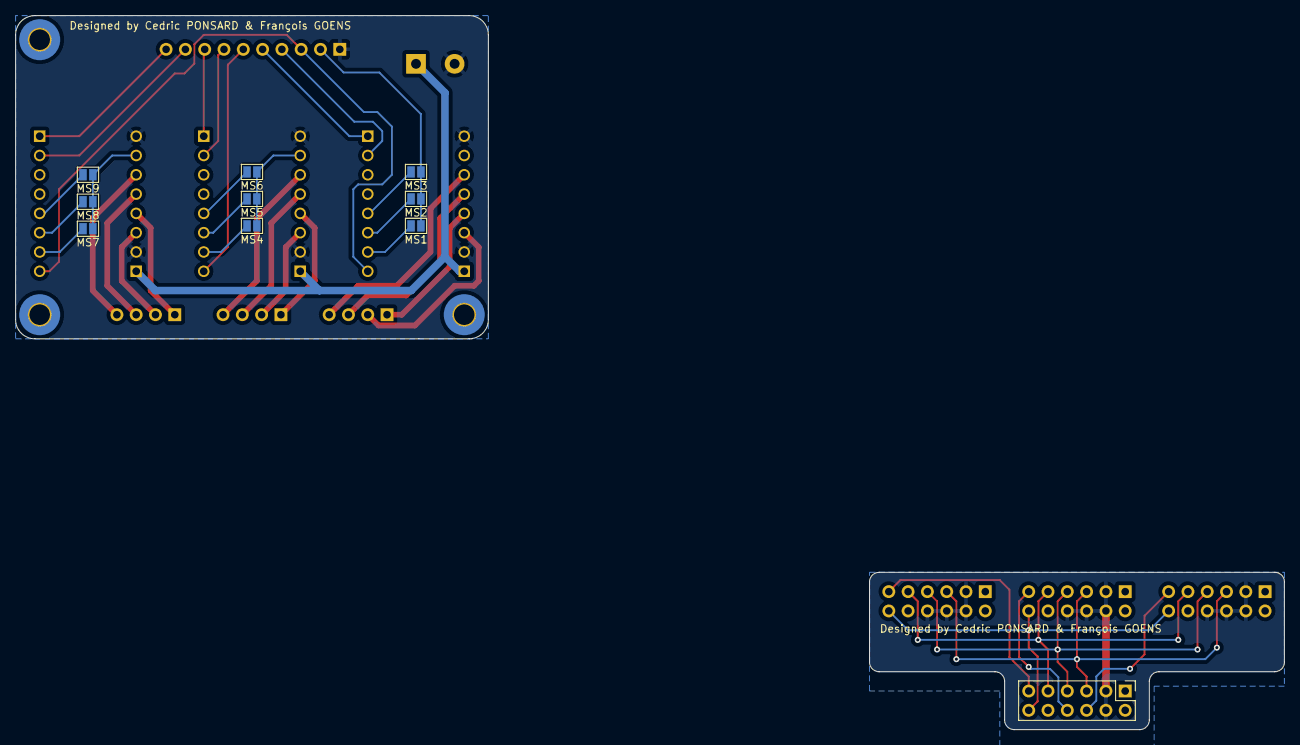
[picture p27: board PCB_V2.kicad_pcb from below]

Board: 2 copper layers, 62.2 x 42.5 mm, 21 parts (10 on the bottom side), 39 nets.

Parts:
J1: Conn_01x10_Socket; PinHeader_1x10_P2.54mm_Vertical
J2, J4, J5: Conn_01x04_MountingPin; PinHeader_1x04_P2.54mm_Vertical
J3: Conn_01x02; TerminalBlock_Phoenix_MKDS-1,5-2-5.08_1x02_P5.08mm_Horizont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
J6: Conn_02x06_Odd_Even; PinHeader_2x06_P2.54mm_Vertical
J7, J8, J9: Conn_02x06_Odd_Even; PinSocket_2x06_P2.54mm_Vertical
MS1, MS2, MS3, MS4, MS5, MS6, MS7, MS8, MS9: SolderJumper_2_Open; SolderJumper-2_P1.3mm_Open_Pad1.0x1.5mm
U1, U2, U3: TMC2208_SILENTSTEPSTICK; MODULE_TMC2208_SILENTSTEPSTICK

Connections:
CS1: J6.11, J9.11
CS2: J6.8, J8.11
CS3: J6.6, J7.11
DIR1: J1.5, U1.JP1_1 (DIR)
DIR2: J1.8, U2.JP1_1 (DIR)
DIR3: J1.10, U3.JP1_1 (DIR)
EN1/3: J1.3, U1.JP1_8 (EN), U3.JP1_8 (EN)
EN2: J1.6, U2.JP1_8 (EN)
GND: J1.1, J3.2, J6.3, J6.4, J7.3, J7.4, J7.6, J7.8, J8.3, J8.4, J8.6, J8.8, J9.3, J9.4, J9.6, J9.8, U1.JP2_2 (GND), U1.JP2_8 (GND), U2.JP2_2 (GND), U2.JP2_8 (GND), U3.JP2_2 (GND), U3.JP2_8 (GND)
INT: J6.12, J7.12, J8.12, J9.12
MISO: J6.7, J7.7, J8.7, J9.7
MOSI: J6.9, J7.9, J8.9, J9.9
unnamed: J2.1, U1.JP2_4 (OA1)
unnamed: J2.2, U1.JP2_3 (OA2)
unnamed: J2.3, U1.JP2_5 (OB1)
unnamed: J2.4, U1.JP2_6 (OB2)
unnamed: J3.1, U1.JP2_1 (VM), U2.JP2_1 (VM), U3.JP2_1 (VM)
unnamed: J4.1, U2.JP2_4 (OA1)
unnamed: J4.2, U2.JP2_3 (OA2)
unnamed: J4.3, U2.JP2_5 (OB1)
unnamed: J4.4, U2.JP2_6 (OB2)
unnamed: J5.1, U3.JP2_4 (OA1)
unnamed: J5.2, U3.JP2_3 (OA2)
unnamed: J5.3, U3.JP2_5 (OB1)
unnamed: J5.4, U3.JP2_6 (OB2)
unnamed: MS1.2 (B), U1.JP1_7 (MS1)
unnamed: MS2.2 (B), U1.JP1_6 (MS2)
unnamed: MS3.2 (B), U1.JP1_5 (PDN/UART2)
unnamed: MS4.2 (B), U2.JP1_7 (MS1)
unnamed: MS5.2 (B), U2.JP1_6 (MS2)
unnamed: MS6.2 (B), U2.JP1_5 (PDN/UART2)
unnamed: MS7.2 (B), U3.JP1_7 (MS1)
unnamed: MS8.2 (B), U3.JP1_6 (MS2)
unnamed: MS9.2 (B), U3.JP1_5 (PDN/UART2)
SCK: J6.5, J7.5, J8.5, J9.5
STEP1: J1.4, U1.JP1_2 (STEP)
STEP2: J1.7, U2.JP1_2 (STEP)
STEP3: J1.9, U3.JP1_2 (STEP)
VDD: J1.2, J6.1, J6.2, J7.1, J7.2, J8.1, J8.2, J9.1, J9.2, MS1.1 (A), MS2.1 (A), MS3.1 (A), MS4.1 (A), MS5.1 (A), MS6.1 (A), MS7.1 (A), MS8.1 (A), MS9.1 (A), U1.JP2_7 (VIO), U2.JP2_7 (VIO), U3.JP2_7 (VIO)

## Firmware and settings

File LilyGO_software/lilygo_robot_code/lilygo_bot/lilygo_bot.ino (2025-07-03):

#include <SPI.h>
#include <LoRa.h>
#include <Arduino.h>
#include <Wire.h>
#include <WiFi.h>

#include "motor_engine.h"

#define BAND 433E6
#define CONFIG_MOSI 27
#define CONFIG_MISO 19
#define CONFIG_CLK  5
#define CONFIG_NSS  18
#define CONFIG_RST  23
#define CONFIG_DIO0 26

#define SDCARD_MOSI 15
#define SDCARD_MISO 2
#define SDCARD_SCLK 14
#define SDCARD_CS   13

#define I2C_SLAVE_ADDR 0x40

// trapezoidal speed command parametter for turning, migration on GRiSP for this part
#define max_turn_speed 80
#define turn_acc 400 

const char* ssid = "RobotNet";
const char* password = "oui123456";

WiFiServer server(80);

float I2C_command[2] = {0.0, 0.0}; // value received from GRiSP : {wheels acceleration , turn speed}

float freq_lim [13] = {300,200,175,150,125,100,90,80,70,60,50,40,30};
int size_test_freq = sizeof(freq_lim)/sizeof(freq_lim[0]);
int index_lim = 0;

// time mesure variable
unsigned long t_GRiSP;
unsigned long t_LORA;
unsigned long t_test;
unsigned long t_ESP;

// freq and period variable
float dt_GRiSP = 10;
float freq_GRiSP = 200;
float dt_ESP = 0;

// control byte received
byte cmd = 0; // received from LoRa communication and transfered to GRiSP
byte GRiSP_flags = 0; // Received from GRiSP

//control flag
bool new_cmd =false;
bool test = false;
bool disturb = false;
bool ext_end = true;


void setup() {
  Serial.begin(115200);

  setup_wifi();

  setup_LoRa();

  setup_I2C_slave();

  setup_motor();

  // time init
  t_GRiSP = millis();
  t_LORA = t_GRiSP;
  t_ESP = t_GRiSP;
}


void loop() {
  unsigned long new_t_ESP = millis();
  dt_ESP = (new_t_ESP - t_ESP) / 1000.0;
  t_ESP = new_t_ESP;
  LoRa_receiver();
  Event_handle();
  delay(1);
}

void setup_wifi(){
  Serial.println("[ROBOT] RobotAP setting up ...");
  WiFi.softAP(ssid, password, 1, false, 8);

  IPAddress IP = WiFi.softAPIP();
  Serial.print("[ROBOT] AP IP address : ");
  Serial.println(IP);
  server.begin();
  Serial.println("[ROBOT] RobotAP ready !");
}

void setup_LoRa(){
  Serial.println("[ROBOT] LoRa setting up ...");
  SPI.begin(CONFIG_CLK, CONFIG_MISO, CONFIG_MOSI, CONFIG_NSS);
  LoRa.setPins(CONFIG_NSS, CONFIG_RST, CONFIG_DIO0);
  if (!LoRa.begin(BAND)) {
    Serial.println("[ROBOT] Starting LoRa failed!");
    while (1);
  }
  Serial.println("[ROBOT] LoRa Ready !");
}

void setup_I2C_slave(){
  // I2C Slave init, work with IRQ so no need to incorporate into the main loop
  Wire.begin(I2C_SLAVE_ADDR);
  Wire.onReceive(GRiSP_receiver);
  Wire.onRequest(GRiSP_sender);
}

void setup_motor(){
  // motor init, works on core n°2
  engine_init();
  delay(1000);
  set_speed(0, 0);
  set_acceleration(0, 0);
}

void GRiSP_receiver(int howMany) {
  if(howMany == 5){ // check if the packet match the expected lenght
    unsigned long new_t_GRiSP = millis();
    dt_GRiSP = (new_t_GRiSP - t_GRiSP) / 1000.0;
    freq_GRiSP = freq_GRiSP * 0.99 + 1.0 / dt_GRiSP * 0.01;
    t_GRiSP = new_t_GRiSP;

    byte A;
    byte B;
    if (Wire.available()) {

      // read and decode the wheel acceleration
      A = Wire.read();
      B = Wire.read();
      I2C_command[0] = decoder(A, B);

      // read and decode the differential turn speed
      A = Wire.read();
      B = Wire.read();
      I2C_command[1] = decoder(A, B);

      // read the flags
      GRiSP_flags = Wire.read();
    }

    //set acceleration
    if(!disturb && bitRead(GRiSP_flags, 4) && !bitRead(GRiSP_flags, 6)){
      set_acceleration(I2C_command[0], I2C_command[0]);
    }

    // Free fall, null wheel speed
    if(bitRead(GRiSP_flags, 6)){ 
      set_acceleration(0, 0);
      set_speed(0, 0);
    }

    // extension/retraction of the rising system
    if(bitRead(GRiSP_flags, 5)){
      ext_end = stand(-48,30.0);
    } else {
      ext_end = stand(0,30.0);
    }

    // wheel counter rotation activation and direction selection during rise
    int stand_speed_dir = 0;
    if(!bitRead(GRiSP_flags, 4)){ // if down
      stand_speed_dir = (bitRead(GRiSP_flags, 3)) ? -1 : 1;
    }
    raise_dir(stand_speed_dir); // -1 back, 0 null, 1 front
  }

  // Empty the stack
  while(Wire.available()){
    Wire.read();
  }
}

void GRiSP_sender() { 
  byte v[5];
  float* speeds = get_speed();
  encoder(v, speeds[0]);
  encoder(v+2, speeds[2]);
  
  // control byte send to GRiSP witth : finsish extension/retraction flag and the command inputs
  v[4] = (cmd & 127) | (is_ready() * 128);
  
  //send 
  Wire.write((byte*) v, sizeof(v));
}

double decoder(byte X, byte Y) {
  // decode half float to double

  byte A = (X & 192);
  if ((A & 64) == 0) A = A | 63;  // fill the missing exponnent bytes with the right value
  byte B = ((X << 2) & 252) | ((Y >> 6) & 3);
  byte C = ((Y << 2) & 252);

  byte vals[] = { 0x00, 0x00, 0x00, 0x00, 0x00, C, B, A };
  double d = 0;
  memcpy(&d, vals, 8);

  return d;
}

void encoder(byte* res, double X){
  // encode double to half float 
  byte vals[8];
  memcpy(vals, &X,8);
  byte A = vals[7];
  byte B = vals[6];
  byte C = vals[5];
  
  res[0] = (A&192)|((B>>2)&63);
  res[1] = ((B<<6)&192)|((C>>2)&63);
  
  return ;
}

void LoRa_receiver(){
  // receiption of LoRa packets
  if (LoRa.parsePacket()) {
    if(LoRa.available()>=2){
      byte cmd1 = LoRa.read();
      byte cmd2 = LoRa.read();
      if(cmd1 == cmd2){
        cmd = cmd1;
        new_cmd = true;
      }
      Serial.println(cmd1);
      Serial.println(cmd2);
    }
    while (LoRa.available()){
      LoRa.read();
    }
  }
}

void Event_handle(){

  //emergency stop 
  emergency(!bitRead(cmd, 7) || !bitRead(GRiSP_flags, 7));
  if (!bitRead(cmd, 7) || !bitRead(GRiSP_flags, 7)){
    set_acceleration(0, 0);
    set_speed(0, 0);
  } 


  // start test procedure
  if(bitRead(cmd, 5)){
    test = true;
    t_test = millis();
  }
  if(test){
    //start the disturbance 500ms to let the record start
    if(millis()> t_test + 500){ 
      //disturb = true;
      //set_acceleration(40, 40);
    }
    // the disturbance is only applied between t=500 and t=800 
    if(millis()> t_test + 800){ 
      disturb = false;
      test = false;
    }
  }

  set_turn(I2C_command[1]);

  new_cmd =false;
}

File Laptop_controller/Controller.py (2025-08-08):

import pygame
import pygame_gui
import sys
import numpy as np
import serial
from Server import Server
from components.Room import Room
from components.Robot import Robot
from pathlib import Path
import time

class User_interface:

    # App General State
    RESIZE = 3.5 # Resizing factor for the rooms
    running = True # True until quit command received
    image_dict = {} # Contains all the images object
    rect_dict = {} # Contains all the images rect

    # Pop Up
    in_popup = False # True if there's an active popup
    active_popup = None # Actual pop-up object
    UI_elements = {} # Elements of the current popup
    temp_origin = None # Used to keep track of the origin button in a popup

    # Robot controll
    x = 0 # Robot command
    string = "" # String to be printed on screen
    

    # App Room state
    room_grid = ((0,0),(0,0)) # Building grid (from top left to bottom right)
    rooms = [] # List of defined rooms
    sensor = [] # List of defined sensors

    # Predefined trajectory
    trajectory = [] # List of predefined commands
    trajectory_idx = 0 # Command index
    current_action = "" # Name of the current command
    action_start_time = 0 # Time at the start of the trajectory
    action_duration = 0 # Total time duration of the command
    is_trajectory_started = False # Set to true when the trajectory begins
    timer = 0 # Keeps track of the time since started

    # Robot UI
    robot = None # Robot object

    # Robot state
    message = 0  #Message to send to the robot
    run = True 
    stand = False
    kalman = True
    release_space = True
    release_enter = True
    release_t = True
    release_tab = True

    # Saved Files
    saved_files = []
    
    def __init__(self, IP, BRD_IP, trajectory):

        pygame.init()
        self.ser = serial.Serial(port="/dev/ttyACM0", baudrate=115200)
        info = pygame.display.Info()
        self.WIDTH, self.HEIGHT = info.current_w, info.current_h

        
        self.screen = pygame.display.set_mode((self.WIDTH, self.HEIGHT), pygame.RESIZABLE)
        pygame.display.set_caption("Robot Controller")

        self.manager = pygame_gui.UIManager((self.WIDTH, self.HEIGHT))
        self.clock = pygame.time.Clock()
        self.clock.tick(200)

        self.server = Server(IP, BRD_IP)
        self.defined_trajectory(trajectory)

        self.load_figures()

    def load_figures(self): # Loads all the images that will appear on screen
        arrow_img = pygame.image.load('./img/arrow.png')
        arrow_img = pygame.transform.scale(arrow_img, (arrow_img.get_width() // 4, arrow_img.get_height() // 4))

        circle_img = pygame.image.load('./img/point.png')
        circle_img = pygame.transform.scale(circle_img, (circle_img.get_width() // 2, circle_img.get_height() // 2))

        stop_img = pygame.image.load('./img/Stop_sign.png')
        stop_img = pygame.transform.scale(stop_img, (stop_img.get_width() // 10, stop_img.get_height() // 10))

        robot = pygame.image.load('./img/Robot.png')
        robot = pygame.transform.scale(robot, (robot.get_width()//6, robot.get_height()//6))

        plus_img = pygame.image.load('./img/plus.png')
        plus_img = pygame.transform.scale(plus_img, (plus_img.get_width() // 5, plus_img.get_height() // 5))

        minus_img = pygame.image.load('./img/minus.png')
        minus_img = pygame.transform.scale(minus_img, (minus_img.get_width() // 5, minus_img.get_height() // 5))

        start_img = pygame.image.load('./img/button_start.png')
        start_img = pygame.transform.scale(start_img, (start_img.get_width(), start_img.get_height()))

        start_img_pressed = pygame.image.load('./img/start_pressed.png')
        start_img_pressed = pygame.transform.scale(start_img_pressed, (start_img_pressed.get_width(), start_img_pressed.get_height()))

        save_img = pygame.image.load('./img/button_save.png')
        save_img = pygame.transform.scale(save_img, (save_img.get_width(), save_img.get_height()))

        load_img = pygame.image.load('./img/button_load.png')
        load_img = pygame.transform.scale(load_img, (load_img.get_width(), load_img.get_height()))

        place_robot = pygame.image.load('./img/button_place_robot.png')
        place_robot = pygame.transform.scale(place_robot, (place_robot.get_width(), place_robot.get_height()))

        zoom_in = pygame.image.load('./img/zoom_in.png')
        zoom_in = pygame.transform.scale(zoom_in, (zoom_in.get_width()//8, zoom_in.get_height()//8))

        zoom_out = pygame.image.load('./img/zoom_out.png')
        zoom_out = pygame.transform.scale(zoom_out, (zoom_out.get_width()//8, zoom_out.get_height()//8))

        self.image_dict["arrow"] = arrow_img
        self.image_dict["circle"] = circle_img
        self.image_dict["stop"] = stop_img
        self.image_dict["plus_L_0"] = plus_img
        self.image_dict["minus"] = minus_img
        self.image_dict["start"] = start_img
        self.image_dict["save"] = save_img
        self.image_dict["load"] = load_img
        self.image_dict["place_robot"] = place_robot
        self.image_dict["start_pressed"] = start_img_pressed
        self.image_dict["zoom_in"] = zoom_in
        self.image_dict["zoom_out"] = zoom_out
        self.image_dict["robot"] = robot
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

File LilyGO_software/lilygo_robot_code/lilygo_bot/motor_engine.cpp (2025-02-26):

#include "motor_engine.h"
TaskHandle_t Motor_engine_task;

int long total_stepA = 0;
int long total_stepB = 0;
int long total_stepC = 0;

//motor dir
int dirA = 0;
int dirB = 0;
int dirC = 0;

//motor dt
int dt_MA = 0;
int dt_MB = 0;
int dt_MC = 0;

//motor avance speed, rot/s
float v_MA = 0;
float v_MB = 0;
float v_MC = 0;

// wheel counter rotation speed during rise, rot/sec
float v_MA_rise = 0;
float v_MC_rise= 0;
int wheel_raise_dir = 0;

// Total wheel speed
float v_tot_A = 0;
float v_tot_B = 0;
float v_tot_C = 0;

float v_diff =0.0;

//motor accelerations, only applied on motor avance speed, rot/s²
float a_MA = 0;
float a_MB = 0;
float a_MC = 0;

//motor dist
float total_dist_A = 0;
float total_dist_B = 0;
float total_dist_C = 0;

//motor freq
double f_MA = 0;
double f_MB = 0;
double f_MC = 0;

//Rise system parameters
int target_step = 0;
float Speed_stand =0;

float v_max_ang = v_max /(PI * diameter);

void engine_init() {

  pinMode(MOTOR_AC_EN_PIN, OUTPUT);
  pinMode(MOTOR_B_EN_PIN, OUTPUT);
  digitalWrite(MOTOR_AC_EN_PIN, LOW);
  digitalWrite(MOTOR_B_EN_PIN, LOW);

  pinMode(MOTOR_A_STEP_PIN, OUTPUT);
  pinMode(MOTOR_B_STEP_PIN, OUTPUT);
  pinMode(MOTOR_C_STEP_PIN, OUTPUT);
  digitalWrite(MOTOR_A_STEP_PIN, LOW);
  digitalWrite(MOTOR_B_STEP_PIN, LOW);
  digitalWrite(MOTOR_C_STEP_PIN, LOW);

  pinMode(MOTOR_A_DIR_PIN, OUTPUT);
  pinMode(MOTOR_B_DIR_PIN, OUTPUT);
  pinMode(MOTOR_C_DIR_PIN, OUTPUT);
  digitalWrite(MOTOR_A_DIR_PIN, LOW);
  digitalWrite(MOTOR_B_DIR_PIN, LOW);
  digitalWrite(MOTOR_C_DIR_PIN, HIGH);


  xTaskCreatePinnedToCore(
    Motor_engine,       /* Task function. */
    "Motor_engine",     /* name of task. */
    10000,              /* Stack size of task */
    (void*)NULL,        /* parameter of the task */
    1,                  /* priority of the task */
    &Motor_engine_task, /* Task handle to keep track of created task */
    1);                 /* pin task to core 1 */
}


void Motor_engine(void* Parameters) {
  //setup
  Serial.print("Motor Engine running on core ");
  Serial.println(xPortGetCoreID());


  unsigned long t_MA = 0;
  unsigned long t_MB = 0;
  unsigned long t_MC = 0;

  unsigned long t_motor = micros();
  unsigned long dt_motor;
  unsigned long new_t_motor;

  //loop
  while (true) {

    //time calculation
    new_t_motor = micros();
    dt_motor = new_t_motor - t_motor;
    t_motor = new_t_motor;
    t_MA += dt_motor;
    t_MB += dt_motor;
    t_MC += dt_motor;


    // incrementation of the stepper motors 
    if (dirA != 0 && t_MA > dt_MA) { 
      digitalWrite(MOTOR_A_STEP_PIN, HIGH);
      total_stepA += dirA;
      t_MA = 0;
    } else {
      digitalWrite(MOTOR_A_STEP_PIN, LOW);
    }

    if (dirB != 0 && t_MB > dt_MB) {
      digitalWrite(MOTOR_B_STEP_PIN, HIGH);
      total_stepB += dirB;
      t_MB = 0;
    } else {
      digitalWrite(MOTOR_B_STEP_PIN, LOW);
    }

    if (dirC != 0 && t_MC > dt_MC) {
      digitalWrite(MOTOR_C_STEP_PIN, HIGH);
      total_stepC += dirC;
      t_MC = 0;
    } else {
      digitalWrite(MOTOR_C_STEP_PIN, LOW);
    }

    engine_update(dt_motor); // uptate each motor step period
  }
}



void set_speed(float vA, float vC) {
  v_MA = vA/(PI * diameter);
  v_MC = vC/(PI * diameter);
}

void set_angular_speed(float vA, float vC) {
  v_MA = vA;
  v_MC = vC;
}

void set_acceleration(float aA, float aC) {
  a_MA = aA/(PI * diameter);
  a_MC = aC/(PI * diameter);
}

void set_angular_acceleration(float aA, float aC) {
  a_MA = aA;
  a_MC = aC;
}

float list_speed[3] = { 0.0, 0.0, 0.0 };
float* get_speed() {
  list_speed[0] = v_tot_A*(PI * diameter);
  list_speed[1] = v_tot_B * lever_ratio;
  list_speed[2] = v_tot_C*(PI * diameter);
  return list_speed;
}

float list_dist[3] = { 0.0, 0.0, 0.0 };
float* get_dist() {
  list_dist[0] = total_stepA * 1.0 / (steps * microsteps) * diameter * PI;
  list_dist[1] = total_stepB * 1.0 / (steps * microsteps) * lever_ratio;
  list_dist[2] = total_stepC * 1.0 / (steps * microsteps) * diameter * PI;
  return list_dist;
}

//low speed loop
void engine_update(unsigned long dt_loop) { 

  //acceleration calculation of motor A with limit to +/- vmax
  v_MA += a_MA * dt_loop * 1e-6 ;
  if (v_MA > v_max_ang) {
    v_MA = v_max_ang;
  } else if (v_MA < -v_max_ang) {
    v_MA = -v_max_ang;
  }

  //displacement calculation of motor B to set the extension/retraction speed 
  //and the wheel counter rotation 
  if (total_stepB > target_step){
    v_MB = Speed_stand / lever_ratio;
    v_MA_rise = Speed_stand * wheel_raise_dir;
    v_MC_rise = Speed_stand * wheel_raise_dir;
  } else if (total_stepB < target_step){
    v_MB = -Speed_stand / lever_ratio;
    v_MA_rise = -Speed_stand * wheel_raise_dir;
    v_MC_rise = -Speed_stand  * wheel_raise_dir;
  } else {
    v_MB = 0;
    v_MA_rise = 0;
    v_MC_rise = 0;
  }
  
  //acceleration calculation of motor A with limit to +/- vmax
  v_MC += a_MC * dt_loop * 1e-6;
  if (v_MC > v_max_ang) {
    v_MC = v_max_ang;
  } else if (v_MC < -v_max_ang) {
    v_MC = -v_max_ang;
  }
  
  //total speeds 
  v_tot_A = v_MA + v_diff + v_MA_rise;
  v_tot_B = v_MB;
  v_tot_C = v_MC - v_diff + v_MC_rise;


  //compute freq from speed
  f_MA = v_tot_A * steps * microsteps;
  f_MB = v_tot_B * steps * microsteps;
  f_MC = v_tot_C * steps * microsteps;

  //compute the increment period from freq and set the direction
  if (f_MA < 0) {
    dt_MA = 1e6 / abs(f_MA);
    digitalWrite(MOTOR_A_DIR_PIN, HIGH);
    dirA = 1;
  } else if (f_MA > 0) {
    dt_MA = 1e6 / abs(f_MA);
    digitalWrite(MOTOR_A_DIR_PIN, LOW);
    dirA = -1;
  } else {
    dirA = 0;
  }


  if (f_MB > 0) {
    dt_MB = 1e6 / abs(f_MB);
    digitalWrite(MOTOR_B_DIR_PIN, LOW);
    dirB = -1;
  } else if (f_MB < 0) {
    dt_MB = 1e6 / abs(f_MB);
    digitalWrite(MOTOR_B_DIR_PIN, HIGH);
    dirB = 1;
  } else {
    dirB = 0;
  }

  if (f_MC > 0) {
    dt_MC = 1e6 / abs(f_MC);
    digitalWrite(MOTOR_C_DIR_PIN, HIGH);
    dirC = -1;
  } else if (f_MC < 0) {
    dt_MC = 1e6 / abs(f_MC);
    digitalWrite(MOTOR_C_DIR_PIN, LOW);
    dirC = 1;
  } else {
    dirC = 0;
  }
}

void reset_dist() { //reset function
  total_stepA = 0;
  total_stepB = 0;
  total_stepC = 0;
}

void set_turn(float angular_speed){ // apply a differential speed on the wheel to turn
  v_diff = (lenght_btw_wheels*PI*angular_speed / (180.0*2))/(PI * diameter) ;
}

void emergency(bool stop){ //shut off the power 
  if(stop){
    digitalWrite(MOTOR_AC_EN_PIN, HIGH);
    digitalWrite(MOTOR_B_EN_PIN, HIGH);
  }else{
    digitalWrite(MOTOR_AC_EN_PIN, LOW);
    digitalWrite(MOTOR_B_EN_PIN, LOW);
  }
}         

bool stand(float angle, float speed){
  target_step = angle/ (360 * lever_ratio) * steps * microsteps;
  Speed_stand = speed*1.0/360.0 ; // go from deg/s to rot/s
  return total_stepB == target_step;
}

void raise_dir(int dir){ // Use to specify the wheel counter rotation direction during raise/fall 
  wheel_raise_dir = dir;
}

bool is_ready(){
  return total_stepB == target_step;
}

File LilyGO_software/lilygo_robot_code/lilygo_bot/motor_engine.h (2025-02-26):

#pragma once

//#include <stdint.h>
#include <Arduino.h>

#define sgn(x) ((x) < 0 ? -1 : ((x) > 0 ? 1 : 0))



#define MOTOR_AC_EN_PIN 14
#define MOTOR_A_STEP_PIN 12
#define MOTOR_A_DIR_PIN 13
#define MOTOR_B_EN_PIN 15
#define MOTOR_B_STEP_PIN 2
#define MOTOR_B_DIR_PIN 0
#define MOTOR_C_STEP_PIN 4
#define MOTOR_C_DIR_PIN 25

#define v_max  100 // speed max, in cm/s
#define microsteps 4
#define steps 400
#define diameter 7 // cm
#define lever_ratio 0.09090909090909090909090909090909 //    12/132
#define lenght_btw_wheels 18.5 // cm



void engine_init();

void Motor_engine(void *);

void engine_update(unsigned long dt_loop);

void set_speed(float,float);

void set_angular_speed(float,float);

void set_acceleration(float,float);

void set_angular_acceleration(float,float);

float* get_speed();

float* get_dist();

void reset_dist();

void set_turn(float);

void emergency(bool);

bool stand(float,float);

void raise_dir(int);

bool is_ready();

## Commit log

2024-08-17 removing prints and unnecessary code
2025-02-23 Init mono repo
    [A.STL, A.dxf, B.STL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]
2025-02-24 [ADD] Electronics + Hardware add
    [0603 Blue.step, 0603 Green.step, 1040320821.stp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]
2025-02-26 modif path des images
2025-02-26 [FIX] Microsteps + motor side
    [lilygo_bot.ino, liygo_user.ino, motor_engine.cpp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]
2025-03-05 [REFACTOR/ADD] Refactored event handler and start sensor adder
2025-03-07 [ADD] Adding sensors to rooms
2025-03-08 [ADD] Initial sensor commit
2025-03-08 [ADD] PCB and motor engine images
2025-03-11 [ADD] Sensor connection to WIFI
2025-03-11 [ADD] Sensor sends IP to computer host
2025-03-11 [ADD] Sensor sends measurements to Laptop
2025-03-11 [ADD] sensor rounds measurements to mm
2025-03-15 [ADD] Error case in wifi setup
2025-03-15 [ADD] Set the sonar frequency to 2Hz
2025-03-15 [ADD] Record the sensors IP
2025-03-15 [ADD] Changed the Sensor IP to just Hello
2025-03-17 [ADD] preview laser cuts
2025-03-18 [ADD] RESIZE param, Grid compute + absolute pos (buggy)
    [RC_robot_UI.py]
2025-03-20 [FIX] Reset control to go in the right direction
    [RC_robot_UI.py]
2025-03-20 [FIX] Correct position computation (still 2/3 cm of error in multi room env)
    [RC_robot_UI.py]
2025-03-25 [ADD] modif in sensor
2025-04-01 [FIX] Fix the two room save bug
    [RC_robot_UI.py]
2025-04-01 [ADD] Sensor waits for start to measure
2025-04-01 [REFACTOR] Sensors are Object in Server, differenciating uni and broadcast in server
2025-04-01 [MODIF] Sensor position are updated not yet sent
2025-04-05 [FIX] Small bug fix where server crashed when sensor wasn't set in a room
    [Server.py]
2025-04-06 [ADD] Sensor starts measurements after random time
2025-04-07 [REFACTOR] sensor parse pos
2025-04-07 [ADD] Device message adder
2025-04-07 [FIX] Problem where the server crashes due to erlang binary format
    [Server.py]
2025-04-08 [ADD] Added Pmod sonar wiki img
2025-04-08 [ADD] Bit of commenting in sensor
2025-04-10 sonar detection + refactor and comments
2025-04-12 [MODIF] Searches for other sensor only once
2025-04-12 [ADD] Sonar send a message before measuring
2025-04-14 [ADD] Sensor discovers server
2025-04-16 [ADD] Server sends exit before killing, sensor resets everything and waits for new server
    [RC_robot_UI.py]
2025-04-16 [DOCU] Sensor documentation
2025-04-17 [FIX] Server Exit (can't restart for now)
    [Server.py]
2025-04-17 [ADD] Possible to put sensors in corners
2025-04-20 [ADD] sending robot pos to sensors
2025-04-21 [ADD] Robot discovery by sensors
2025-04-21 [FIX] Bug with sensor Id
2025-04-21 [MODIF] Changed LEDs meaning
2025-04-21 [ADD] Can define sensor's height
2025-04-21 [ADD] Correct ground distance computed
    [Server.py]
2025-04-21 [FIX] Typo in sensor
2025-04-21 [FIX] Bug with inserting sensors in corners
    [RC_robot_UI.py]
2025-04-21 [ADD] sensor angle computation
2025-04-21 [ADD] Sensor receives angle
2025-04-22 Create Sensor_build
2025-04-22 [REFACTOR] Renamed Sensor_build to Hardware Sensor
    [Iece_change v1.stl, Sensor_piece v12.stl, Support coin_attache v2.stl]
2025-04-22 [REFACTOR] Moved Sensors 3D files in folder
    [Iece_change v1.stl, Sensor_piece v12.stl, Support coin_attache v2.stl]
2025-04-23 [REFACTOR] Sensor
2025-04-23 [DOCU] commented sensor's code
2025-04-23 [DOCU] Sonar_sensor and sensor
2025-04-24 first version of kalman filter
2025-04-27 Second version of kalman filter
2025-04-30 [REFACTOR] step 2 : delete logging, i2C in persistent term
2025-04-30 [REFACTOR] Step 5 : deleted complementary filter
2025-04-30 [REFACTOR] Step 9 : Removed Pid from arguments
2025-05-12 [FIX] small error in LEDS colors
2025-05-18 [WIKI] Sensor FSM
2025-05-19 [FIX] Robot pos update
    [Server.py]
2025-05-19 [FIX] Dist between sensors was in meters
2025-05-20 [MODIF] Upgraded sync between sensors
2025-05-20 [DOCU] Deleted ping print
2025-05-20 [MODIF] No Click to spawn robot, popup instead (not working yet)
    [RC_robot_UI.py]
2025-05-20 [MODIF] Moved other sensor finding in sensor
2025-05-21 [FIX] Sonar Sensor restarts from latest Seq number when crash
2025-05-22 [FIX] Target angle works for sensor slightly up from the ground
2025-05-23 [ADD] Server sends configuration using a thread
2025-05-23 [FIX] Allow mono sensor in room
2025-05-24 [ADD] Robot and sensor succesfully ack their config messages
2025-05-24 [FIX] Corrected bug ins server
    [Server.py]
2025-05-24 [DOCU] Resseted the documentation to match the ones of the sensors
2025-05-26 [DOCU] Modified incorrect SENSOR indentificator to ROBOT
2025-05-26 [FIX] Reactivated serial comm
    [Controller.py]
2025-05-28 [ADD] BUGGY Try to get the robot pos by sonars
2025-05-28 [FIX] Removed server print when exception
    [Server.py]
2025-05-28 [FIX] Remove begin csv
    [Server.py]
2025-06-02 [WIKI] Add sensor img
2025-06-02 [ADD] Computes Ground dist only if H > Robot height
2025-06-02 [ADD] Computes pos based on sonars (A lot of noise, normal ?)
2025-06-04 [FIX] Beginning fix kalman sensor
2025-06-10 [FIX] Good position using sonars, still need to select the correct one using room coordinates
2025-06-10 [ADD] Sensors and robot receive rooms limits
2025-06-10 [Kalman_filter] Start new kalman filter
2025-06-10 [Kalman Filter] First version with nav and pos
2025-06-10 [Kalman Filter] Just position without Acc
2025-06-10 [kalman filter] XY with Acc, Test
2025-06-11 [FIX] Correct sonar_sensor + room_infos
2025-06-11 [ADD] Sensors use 300ms timeslots
2025-06-12 [ADD/FIX] Sonar sensor filters out spikes + corrected csv_saver plot
2025-06-12 [kalman filter] UpDate when no intersection
2025-06-12 [kalman filter] UpDate when no interaction
2025-06-12 [kalman filter] position and orientation
2025-06-13 [FIX] Controller plot printing
    [Server.py]
2025-06-14 [kalman filter] Full liaison position angle
2025-06-17 [NEW] ekf filter for no linear system
2025-06-17 [FIX] Correct handling of pos data
    [Controller.py, Server.py]
2025-06-20 [ADD] Exponential smoothing sonars
2025-06-21 [ADD] SPI slave monitor messages
2025-06-22 [kalman filter] Avant gros changement simplification
2025-06-22 [FIX] Multi start robustness
    [Server.py]
2025-07-05 [Kalman] Without Xpred when no sonar
2025-07-05 [Kalman] Separation with values sonars or not
2025-07-06 [MODIF] Upgraded and simplified clock and sonar_sensors
2025-07-07 [MODIF] Working filter sonar
2025-07-08 [FIX] Corrected sonar pos
2025-07-11 [ADD] Sys.config sensor
2025-07-11 [MODIF] Relaxed sonar filters
2025-07-11 [FIX] Kalman verif seq sonar
2025-07-15 [FIX] Corrected sonar ?
2025-07-17 [Switch room] Add switch room in kalman
2025-07-17 [FIX] Switch room sensor
2025-07-29 [ADD/REFACTOR] Switch room done
2025-08-04 [Kalman Filter] Final version
